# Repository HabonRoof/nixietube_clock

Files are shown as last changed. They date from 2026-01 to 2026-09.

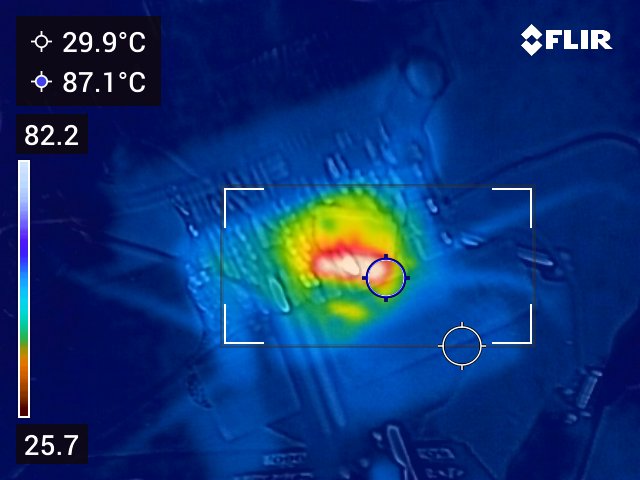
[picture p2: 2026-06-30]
doc/picture/tap_inductor/IR/FLIR0194.jpg

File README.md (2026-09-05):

# Nixie Clock Firmware

Open-source ESP-IDF firmware for a multiplexed Nixie clock powered by an ESP32-S3. Hardware display boards include IN-4 and IN-18 variants; at boot the firmware senses `DISPLAY_TYPE` (GPIO 19) and selects an IN-4 (6) or IN-14 (6/8) drive profile. RGB backlighting, audio playback, battery management, and a built-in web configuration UI are included.

Whether you want to hack on display effects, add CLI tools, improve the web UI, or bring up new hardware, this guide will get you building with [PlatformIO](https://platformio.org/) quickly.

## Features

- **Nixie display** — Multiplexed control via PCA9685 PWM drivers and a 74HC238 anode mux (tube count and chip count follow the detected display-board profile).
- **RGB backlight** — WS2812 addressable LEDs (4 per tube) with static, breath, rainbow, and off effects.
- **Audio** — DFPlayer Mini integration for sound effects and announcements.
- **RTC** — DS3231 for precise timekeeping with periodic resync to ESP32 system time.
- **Web UI** — On-demand config Wi-Fi AP (`NixieClock-XXXX` / `nixie2026`) with HTTP settings; long-press **button 1 + button 2** (3 s) to enter config mode.
- **NTP sync** — Optional home WiFi credentials; daily ~06:00 local brief STA session writes NTP to DS3231 and verifies RTC error < 1 min (retries on failure).
- **Buttons** — Debounced physical inputs for display mode, backlight profile, and interactive modes.
- **Hibernate mode** — Scheduled daily window turns off tubes and LED backlight. Press any button for a 5-second clock preview (tubes at fixed brightness 50, LED off).
- **Idle standby** — After 1 minute without button presses in clock mode, dim nixie and backlight brightness to 25% of the active profile; any button press restores full brightness.
- **Auto cathode anti-poisoning** — Every 15 minutes, run the same cathode-poisoning digit sweep as manual mode, then auto-return to the clock.
- **Serial CLI** — Interactive console for development, diagnostics, and power-rail control.
- **Power management** — BQ25601 battery charger, BQ27441 fuel gauge, and switched HV / DFPlayer rails.
- **Persistent settings** — Clock preferences stored in NVS and restored on boot.
- **Modular architecture** — FreeRTOS daemons coordinated by a central system controller.

## Developing with PlatformIO

This project uses **PlatformIO + ESP-IDF**. You can work from VS Code / Cursor or from the CLI.

### 1. Install tools

1. Install [Git](https://git-scm.com/) and [Python 3](https://www.python.org/downloads/) (needed for the git-version build script).
2. Install either:
   - **Recommended:** [VS Code](https://code.visualstudio.com/) or Cursor with the [PlatformIO IDE](https://platformio.org/install/ide?install=vscode) extension, or
   - [PlatformIO Core (CLI)](https://docs.platformio.org/en/latest/core/installation.html) alone.
   For now, the PlatformIO for cursor is not stable, so I recommand to use VSCode to compile and use Cursor for coding. 

Opening this repo in VS Code / Cursor should prompt you to install the recommended `platformio.platformio-ide` extension (see `.vscode/extensions.json`).

### 2. Clone and open the project

```bash
git clone https://github.com/HabonRoof/nixietube_clock.git
cd nixietube_clock
```

In VS Code / Cursor: **File → Open Folder** and select the repo root (the folder that contains `platformio.ini`).

First build will download the Espressif platform, ESP-IDF toolchain, and dependencies into `.pio/` — expect a few minutes on a clean machine.

### 3. Pick a build environment

Defined in `platformio.ini`:

| Environment | Board | Use case |
| :--- | :--- | :--- |
| `esp32_s3_devkitc_1` | ESP32-S3-DevKitC-1 | General development / bring-up |
| `esp32_s3_nixie` (default) | Custom `esp32-s3-nixie` (`boards/`) | Production Nixie clock board |

Switch the active env in the PlatformIO status bar, or pass `-e <name>` on the CLI.

### 4. Everyday commands

| Action | CLI | VS Code / Cursor (PlatformIO) |
| :--- | :--- | :--- |
| Build | `pio run` | Build (✓) |
| Flash | `pio run -t upload` | Upload (→) |
| Serial monitor | `pio run -t monitor` | Serial Monitor (🔌) |
| Build + flash + monitor | `pio run -t upload && pio run -t monitor` | Upload and Monitor |
| Clean | `pio run -t clean` | Clean |
| Build for Nixie board | `pio run -e esp32_s3_nixie` | Select `esp32_s3_nixie` env, then Build |

Serial monitor is **115200 baud** (8N1). After connect you should see boot logs and the CLI prompt `nixie_clock> `.

Useful PlatformIO tips:

```bash
# Rebuild from a clean slate
pio run -t clean && pio run

# Flash a specific env, then open the monitor
pio run -e esp32_s3_devkitc_1 -t upload
pio run -t monitor

# List detected serial ports if upload fails
pio device list
```

The build embeds the current git commit hash via `generate_git_version.py` (`get_fw_version` in the CLI).

### 5. Verify you are up and running

1. Flash firmware and open the serial monitor.
2. Type `help` at `nixie_clock> ` to list CLI commands.
3. **Long-press button 1 + button 2** (3 s together) to open the config Wi-Fi AP. Nixie tubes show a 4-digit session code; join `NixieClock-XXXX` (password `nixie2026`) and open `http://192.168.8.8/`.

If something fails to compile or upload, check:

- Use USB Type-A to Type-C cable, the hardware is not support to connect C to C cable for uploading.
- The board is in download mode / USB cable is data-capable.
- The correct env is selected (`esp32_s3_devkitc_1` vs `esp32_s3_nixie`).
- Python can run `generate_git_version.py` from the project root.
- Antivirus or missing udev/driver issues are not blocking the serial port (Windows often needs the CP2102 USB serial driver).

### 6. Where to start hacking

| Goal | Start here |
| :--- | :--- |
| Boot / wiring of subsystems | `src/main.cpp` |
| Mode logic, time, settings | `src/system_controller.*` |
| Tubes / LED effects | `src/daemons/display_daemon.*` |
| Buttons | `src/daemons/input_daemon.*` |
| Audio / DFPlayer | `src/daemons/audio_daemon.*` |
| Serial commands | `src/daemons/cli_daemon.*` |
| Web settings UI | `src/web_server.cpp`, `src/web_page.cpp` |
| Device drivers | `lib/drivers/`, `lib/include/` |
| Shared messages / state | `lib/include/message_types.h`, `src/system_state.*` |

## Software Structure

The firmware is split into clear layers so new contributors can find the right file quickly.

```text
┌─────────────────────────────────────────────────────────────┐
│  Interfaces                                                 │
│    WebServer  ·  CliDaemon  ·  InputDaemon (buttons)        │
├─────────────────────────────────────────────────────────────┤
│  Coordination                                               │
│    SystemController  ·  SystemState (NVS)                   │
├─────────────────────────────────────────────────────────────┤
│  FreeRTOS daemons                                           │
│    DisplayDaemon  ·  AudioDaemon                            │
├─────────────────────────────────────────────────────────────┤
│  App drivers / services                                     │
│    NixieDriver · LedDriver · AudioDriver                    │
│    PowerController · ChargerController · GasgaugeService    │
├─────────────────────────────────────────────────────────────┤
│  Hardware drivers (lib/drivers)                             │
│    PCA9685 · WS2812 · DFPlayer · DS3231 · BQ25601 · BQ27441 │
└─────────────────────────────────────────────────────────────┘
```

### Directory map

```text
nixietube_clock/
├── platformio.ini          # PlatformIO envs, ESP-IDF, build flags
├── boards/                 # Custom board JSON (esp32-s3-nixie)
├── generate_git_version.py # Embeds git hash into the firmware
│
├── src/                    # Application code (what most PRs touch)
│   ├── main.cpp            # Boot: NVS, drivers, start daemons
│   ├── system_controller.* # Central coordinator (time, modes, settings)
│   ├── system_state.*      # Thread-safe settings / battery / time + NVS
│   ├── web_server.*        # Wi-Fi AP + HTTP API
│   ├── web_page.*          # Embedded settings HTML/JS
│   ├── settings_json.*     # ClockSettings ↔ nested JSON
│   ├── web_json.*          # HTTP JSON body / response helpers
│   ├── nixie_driver.*      # High-level tube multiplexing
│   ├── led_driver.*        # High-level WS2812 control
│   ├── audio_driver.*      # High-level DFPlayer wrapper
│   ├── power_controller.*  # HV / DFPlayer rail switching
│   ├── charger_controller.*
│   ├── gasgauge_service.*
│   ├── color_model.cpp     # Color helpers for backlight
│   └── daemons/
│       ├── display_daemon.*  # Nixie + LED effects @ 50 Hz
│       ├── audio_daemon.*    # Async audio commands
│       ├── input_daemon.*    # Button debounce → SystemController
│       └── cli_daemon.*      # Serial console
│
├── lib/
│   ├── include/            # Public headers / interfaces / message types
│   └── drivers/            # Low-level IC drivers (I2C/UART/RMT/GPIO)
│       ├── pca9685/
│       ├── ws2812/
│       ├── dfplayer/
│       ├── ds3231/
│       ├── bq25601/
│       ├── bq27441/
│       ├── i2c_bus/
│       ├── power_switch/
│       └── display_board/
│
├── hardware/               # KiCad schematics & PCBs (main, display, HV)
├── test/                   # Manual CLI tests and component experiments
└── doc/                    # Datasheets, photos, architecture drawings
    ├── web_api.md          # HTTP JSON API schemas
    ├── state_machine.drawio  # Behavioral modes (keep in sync with firmware)
    └── structure.drawio    # Early aspirational block diagram (outdated)
```

### Responsibility cheat sheet

| Module | Role |
| :--- | :--- |
| `main.cpp` | Creates drivers/services, wires dependencies, starts tasks |
| `SystemController` | Owns RTC sync, display mode / backlight / alarm logic; single writer for settings |
| `SystemState` | Shared snapshots + NVS load/save |
| `DisplayDaemon` | Tube digits, LED effects, 50 Hz update loop |
| `AudioDaemon` | Plays/pauses tracks; powers DFPlayer rail via `PowerController` |
| `InputDaemon` | Polls/debounces BTN_0–2 and posts presses to `SystemController` |
| `CliDaemon` / `WebServer` | External control surfaces; request settings through `SystemController` |
| `lib/drivers/*` | Talk to chips; keep bus/register details out of app logic |

Cross-task communication uses FreeRTOS queues and types in `lib/include/message_types.h`. Prefer posting messages (or `SystemController::request_settings_update()`) over reaching into another daemon’s private state.

## Hardware Configuration

Pin assignments are defined in `src/system_controller.cpp` and `lib/drivers/power_switch/gpio_power_switch.h`.

| Peripheral | Pin Name | GPIO | Description |
| :--- | :--- | :--- | :--- |
| **I2C** | SDA | GPIO 6 | I2C data (DS3231, PCA9685, BQ25601, BQ27441) |
| | SCL | GPIO 5 | I2C clock (400 kHz) |
| **UART** | TX | GPIO 42 | Audio TX → DFPlayer RX |
| | RX | GPIO 41 | Audio RX ← DFPlayer TX |
| **GPIO** | RTC_INT | GPIO 2 | DS3231 interrupt (active low) |
| | BTN_0 | GPIO 8 | Alarm stop / pomodoro start / divergence re-trigger |
| | BTN_1 | GPIO 12 | Display mode cycle |
| | BTN_2 | GPIO 13 | Backlight profile cycle |
| | PCA_OE | GPIO 4 | PCA9685 output enable (active low) |
| | ANODE_A0–A2 | GPIO 9–11 | 74HC238 anode mux address lines |
| | DISPLAY_TYPE | GPIO 19 | Analog strap for display-board type (ADC2 CH8) |
| | HV_PWR | GPIO 15 | HV power rail enable (via `GpioPowerSwitch`) |
| | DF_PWR | GPIO 16 | DFPlayer power rail enable (via `GpioPowerSwitch`) |
| **RMT** | LED_DATA | GPIO 7 | WS2812 LED data line |

`DISPLAY_TYPE` strap voltages map to firmware profiles: ~0 V → IN-4 (6 tubes, 4× PCA9685); ~1.65 V → IN-14 (8 tubes, 5× PCA9685); ~3.3 V → IN-14 (6 tubes, 4× PCA9685). KiCad projects under `hardware/` include `display_board_in4` and `display_board_in18` (IN-18 boards use the matching strap / profile configured on the PCB).

## Architecture

The firmware runs on FreeRTOS and uses a daemon-based design. `SystemState` holds shared, thread-safe snapshots of settings, battery, and time status.

```mermaid
flowchart TB
    subgraph Interfaces
        Web[WebServer]
        CLI[CliDaemon]
        IN[InputDaemon]
    end

    SC[SystemController]
    DD[DisplayDaemon]
    AD[AudioDaemon]
    CC[ChargerController]
    PC[PowerController]

    Web --> SC
    CLI --> SC
    CLI --> CC
    CLI --> PC
    CLI --> AD
    IN --> SC

    SC --> DD
    SC --> AD
    SC --> SystemState[(SystemState / NVS)]

    DD --> Nixie[NixieDriver / PCA9685]
    DD --> LED[LedDriver / WS2812]
    AD --> Audio[AudioDriver / DFPlayer]
    AD --> PC
    SC --> RTC[DS3231]
    SC --> GG[GasgaugeService / BQ27441]
    CC --> Charger[BQ25601]
    PC --> Rails[HV & DFPlayer rails]
```

### System Controller (`src/system_controller.cpp`)

Central coordinator that:

- Initializes I2C, UART, RMT, and GPIO peripherals.
- Owns the DS3231 RTC and maintains ESP32 system time (UTC).
- Periodically resyncs from the RTC and publishes time status.
- Polls the BQ27441 fuel gauge and updates battery status.
- Dispatches 1 Hz time updates to `DisplayDaemon`.
- Handles button presses from `InputDaemon` (modes, backlight, pomodoro / alarm).
- Accepts thread-safe settings changes from the web UI and CLI.

### Display Daemon (`src/daemons/display_daemon.cpp`)

Manages all visual output:

- Drives Nixie tubes via `NixieDriver` (dedicated high-priority multiplexing task).
- Drives LED backlights via `LedDriver`.
- Runs the LED effects engine (static, breath, rainbow, off).
- Updates hardware at 50 Hz.

#### Display modes (BTN_1 cycle)

Press **BTN_1** to cycle through display modes in this order:

1. **Clock** (`HHMMSS`) — normal time display
2. **Date** (`YYMMDD`) — current date
3. **Pomodoro** — 25-minute work / 5-minute break timer
4. **Divergence meter** — random digit animation (auto-returns to clock)
5. **Cathode poisoning** — digit sweep on all tubes (auto-returns to clock)

**Pomodoro mode:** On entry the display shows `002500` with a static red backlight (brightness follows your profile). Press **BTN_0** to start the countdown; the backlight breathes red during work and green during break. Work and break sessions alternate automatically until you cycle away with **BTN_1**, which restores your backlight profile.

### Input Daemon (`src/daemons/input_daemon.cpp`)

Polls the three front-panel buttons every 20 ms with debounce / inter-press filtering, then posts press events to `SystemController`. **Button 2** short press cycles backlight profiles; **long press button 1 + button 2** (3 s) opens or closes the config Wi-Fi AP. Pin map: `lib/include/button_config.h`.

### Audio Daemon (`src/daemons/audio_daemon.cpp`)

Handles asynchronous audio commands (play, stop, volume) and communicates with the DFPlayer Mini. Uses `PowerController` to switch the DFPlayer power rail.

### Web Server (`src/web_server.cpp`, `src/web_page.cpp`)

On-demand config Wi-Fi AP and embedded HTTP server (active only in config mode):

| Setting | Value |
| :--- | :--- |
| Enter config | Long-press button 1 + button 2 for 3 s (same combo exits when AP is active) |
| SSID | `NixieClock-XXXX` (random 4-digit code each session; shown on Nixie tubes) |
| Password | `nixie2026` |
| AP IP | `192.168.8.8` |
| Timeout | 15 min max, or 2 min after all clients disconnect |

Connect to the AP and open `http://192.168.8.8/`. Use **完成並關閉設定 WiFi** when done.

| Endpoint | Method | Description |
| :--- | :--- | :--- |
| `/` | GET | Settings web UI |
| `/api/settings` | GET/POST | Clock settings (JSON); see [doc/web_api.md](doc/web_api.md) |
| `/api/ap/status` | GET | Config AP SSID, session code, remaining time |
| `/api/ap/stop` | POST | Stop config AP (deauth + shutdown) |
| `/api/wifi` | GET/POST/DELETE | Home WiFi for daily NTP sync |
| `/api/ntp/status` | GET | Last NTP sync status |
| `/api/time` | GET | Local time, RTC status, temperature |
| `/api/audio/*` | GET/POST | MP3 tracks and playback |

Home WiFi credentials enable a brief daily STA session at **06:00 local** for NTP → DS3231 sync (always write, verify RTC within 1 min, retry up to 3×); WiFi is off the rest of the time.

Full schemas: [doc/web_api.md](doc/web_api.md).

Configurable settings include timezone offset, alarm, backlight, nixie brightness/transition, volume, profiles, hibernation, and home WiFi. The web **Light** tab provides live display preview; **Save 1–4** commits a profile. Short-press button 2 to switch profiles on the device.

### CLI Daemon (`src/daemons/cli_daemon.cpp`)

Interactive serial console for development, diagnostics, and factory setup. Connect at **115200 baud** (8N1, no flow control) via USB or UART. The prompt is `nixie_clock> `. Type `help` for a summary of all commands.

```bash
pio run -t monitor
```

#### Display and backlight

| Command | Description |
| :--- | :--- |
| `set_nixie --number <n>` | Display a 6-digit number on the tubes |
| `set_backlight --rgb R,G,B --brightness N` | Set backlight color and brightness (0–255) |

#### Device info

| Command | Description |
| :--- | :--- |
| `get_uuid` | Wi-Fi MAC-based device ID |
| `get_hw_version` | ESP32-S3 chip and board revision |
| `get_fw_version` | Git commit hash and ESP-IDF version |
| `reboot` | Restart the device |

#### RTC and alarm (`rtctool`)

The DS3231 RTC stores **UTC** internally; CLI time and alarm values are **local wall clock** and are converted using the configured timezone offset. Set operations are asynchronous — run `rtctool read` afterward to confirm.

| Subcommand | Description |
| :--- | :--- |
| `rtctool read` | Read local time, UTC epoch, timezone, calibration/OSF status, temperature, and alarm settings |
| `rtctool set_tz <offset_hours>` | Set timezone offset (-12..+14) |
| `rtctool set_time <YYYY-MM-DD HH:MM:SS>` | Calibrate RTC and system clock (marks RTC as calibrated) |
| `rtctool set_alarm <HH:MM:SS> [--enable\|--disable] [--track <n>]` | Set daily alarm time; enables alarm by default |

Example workflow:

```text
nixie_clock> rtctool set_tz 8
nixie_clock> rtctool set_time 2026-07-06 16:30:00
nixie_clock> rtctool set_alarm 07:30:00 --enable --track 1
nixie_clock> rtctool read
```

To disable the alarm without changing its time:

```text
nixie_clock> rtctool set_alarm 07:30:00 --disable
```

#### Power and charging

| Command | Description |
| :--- | :--- |
| `get_bq25601_status` | Read BQ25601 charger status registers |
| `enable_charging` / `disable_charging` | Control battery charging |
| `enable_hv` / `disable_hv` | Control HV power rail |
| `enable_df_power` / `disable_df_power` | Control DFPlayer power rail |

#### DFPlayer audio (`dftool`)

Commands talk to the `AudioDaemon`, which powers the DFPlayer rail automatically when needed. Place MP3 files in an `mp3` folder on the SD card root and name them `0001.mp3`, `0002.mp3`, etc. (up to 9999). Track numbers match the numeric prefix in each filename.

| Subcommand | Description |
| :--- | :--- |
| `dftool list` | List tracks in the SD card `mp3/` folder |
| `dftool status` | Show current track, playback state, and track count |
| `dftool play <track> [--loop]` | Play a track; add `--loop` for repeat |
| `dftool toggle <track>` | Play/pause toggle (same behavior as the web UI) |
| `dftool pause` | Pause playback |
| `dftool resume` | Resume playback |
| `dftool stop` | Stop playback |
| `dftool next` | Play next track |
| `dftool prev` | Play previous track |
| `dftool volume <0-30>` | Set volume (DFPlayer range) |
| `dftool vol_up` / `dftool vol_down` | Step volume up or down |

Example workflow:

```text
nixie_clock> dftool list
nixie_clock> dftool play 1
nixie_clock> dftool status
nixie_clock> dftool pause
nixie_clock> dftool resume
nixie_clock> dftool volume 20
nixie_clock> dftool stop
```

#### Fuel gauge (`ggtool`)

| Subcommand | Description |
| :--- | :--- |
| `ggtool status` | Probe BQ27441 device info and gauging readiness |
| `ggtool read` | Read live SOC, SOH, voltage, and current |
| `ggtool cache` | Read last cached battery values from `SystemState` |
| `ggtool peek <reg_hex> [len]` | Dump raw register bytes |
| `ggtool block [class] [index]` | Dump a 32-byte state block |
| `ggtool config [mAh]` | Configure design capacity |

See `test/test_cli/README.md` for a manual test plan and automated test script.

### Drivers (`lib/drivers/`, `src/*_driver.cpp`)

| Driver | Role |
| :--- | :--- |
| `NixieDriver` | PCA9685 multiplexing; chip/tube count from `display_board_config` profile |
| `LedDriver` | RMT-based WS2812 control |
| `AudioDriver` | High-level DFPlayer Mini interface |
| `Ds3231` | RTC read/write and temperature |
| `Bq25601` | Battery charger IC |
| `Bq27441` | Fuel gauge IC |
| `GpioPowerSwitch` | HV and DFPlayer power-rail switching |

## Development Guide

### Adding a New LED Effect

1. Add a method such as `run_my_effect(uint32_t dt_ms)` in `DisplayDaemon`.
   Use `apply_backlight_to_all(state)` or manipulate `led_driver_` directly.
2. Add an entry to the `LedEffectType` enum in `display_daemon.h`.
3. Update `DisplayDaemon::process_message` to handle the new effect type.
4. Update `DisplayDaemon::update_effects` to call the new method.
5. Expose the effect in the web UI (`web_page.cpp`) and settings schema (`system_state.h`).

### Applying Settings from a New Interface

Use `SystemController::request_settings_update()` so the system controller task remains the sole owner of RTC and settings state. Read current values from `SystemState` and persist with `SystemState::save_settings()`.

### Adding a CLI Command

1. Register parsing / help text in `src/daemons/cli_daemon.cpp`.
2. Prefer calling existing controllers/daemons (`SystemController`, `AudioDaemon`, `PowerController`, …) instead of talking to hardware directly.
3. Document the command in this README under **CLI Daemon**.

## Contributing

Contributions are welcome — effects, CLI tools, web UI polish, driver fixes, docs, and hardware errata all help.

1. Fork the repo and create a feature branch.
2. Build with PlatformIO (`pio run`) and smoke-test on hardware or a DevKit when possible.
3. Keep changes focused; match the existing modular daemon style.
4. Open a pull request describing **what** changed and **how to test** it.

If you are unsure where something belongs, open an issue first — happy to point you at the right module.

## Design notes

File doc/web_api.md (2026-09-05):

# Web API

HTTP JSON API served when the Nixie clock config Wi-Fi AP is active (`NixieClock-XXXX` / `192.168.8.8`). Enter config mode with a **3 s long-press on button 1 + button 2 together**.

All JSON endpoints use `Content-Type: application/json`. Successful mutations return `{"ok": true}`. Errors return HTTP 4xx/5xx with:

```json
{
  "ok": false,
  "error": {
    "code": "invalid_type",
    "field": "alarm.time",
    "message": "must be a string"
  }
}
```

`field` is omitted when the error is not tied to a specific key.

Maximum POST body size: **4096 bytes**.

## Endpoints

| Endpoint | Method | Description |
| :--- | :--- | :--- |
| `/` | GET | Embedded settings web UI (HTML) |
| `/api/settings` | GET | Current persisted settings |
| `/api/settings` | POST | Apply a partial settings update |
| `/api/time` | GET | Live clock readout and RTC health |
| `/api/audio/tracks` | GET | MP3 track list from SD card |
| `/api/audio/status` | GET | Current playback state |
| `/api/audio/play` | POST | Toggle play/pause for a track |
| `/api/ap/status` | GET | Config AP active flag, SSID, password, session code, remaining seconds |
| `/api/ap/stop` | POST | Deauth connected clients and stop config AP |
| `/api/wifi` | GET | Home WiFi SSID (configured flag; password never returned) |
| `/api/wifi` | POST | Save home WiFi credentials to NVS |
| `/api/wifi` | DELETE | Clear home WiFi credentials |
| `/api/ntp/status` | GET | Last NTP sync timestamp and success flag |

## `GET /api/ap/status`

```json
{
  "active": true,
  "session_code": 3847,
  "ssid": "NixieClock-3847",
  "password": "nixie2026",
  "remaining_sec": 842,
  "client_count": 1
}
```

## `POST /api/ap/stop`

Stops the config AP after deauthenticating connected stations. Response: `{"ok": true}`.

## `GET /api/wifi`

```json
{
  "configured": true,
  "ssid": "MyHomeWiFi"
}
```

## `POST /api/wifi`

```json
{
  "ssid": "MyHomeWiFi",
  "password": "secret"
}
```

## `DELETE /api/wifi`

Clears stored home WiFi credentials. NTP scheduled sync is skipped until reconfigured.

## `GET /api/ntp/status`

```json
{
  "configured": true,
  "last_success": true,
  "last_ntp_unix": 1736123456
}
```

## `GET /api/settings`

```json
{
  "schema_version": 1,
  "clock": {
    "timezone_offset_hours": 8,
    "rtc_calibrated": true
  },
  "alarm": {
    "enabled": true,
    "time": "07:30:00",
    "track": 1
  },
  "display": {
    "backlight": {
      "color": { "r": 255, "g": 128, "b": 0 },
      "brightness": 128,
      "effect": "static"
    },
    "nixie": {
      "brightness": 255,
      "transition": "fade"
    }
  },
  "audio": { "volume": 15 },
  "profiles": {
    "active_index": 0,
    "items": [
      { "index": 0, "display": { "...": "..." } }
    ]
  },
  "hibernation": {
    "enabled": false,
    "start": "00:00",
    "end": "07:00"
  }
}
```

### Field reference

| Path | Type | Range / values |
| :--- | :--- | :--- |
| `schema_version` | integer | API schema version (currently `1`) |
| `clock.timezone_offset_hours` | integer | `-12` … `14` |
| `clock.rtc_calibrated` | boolean | `true` after explicit time sync |
| `alarm.enabled` | boolean | |
| `alarm.time` | string | `HH:MM:SS` (local wall clock) |
| `alarm.track` | integer | DFPlayer track number (`1` … `9999`) |
| `display.backlight.color.{r,g,b}` | integer | `0` … `255` |
| `display.backlight.brightness` | integer | `0` … `255` |
| `display.backlight.effect` | string | `static`, `breath`, `rainbow`, `off` |
| `display.nixie.brightness` | integer | `0` … `255` |
| `display.nixie.transition` | string | `instant`, `fade` |
| `audio.volume` | integer | `0` … `30` (DFPlayer hardware range) |
| `profiles.active_index` | integer | `0` … `3` |
| `profiles.items[].index` | integer | Profile slot `0` … `3` |
| `hibernation.enabled` | boolean | |
| `hibernation.start` / `end` | string | `HH:MM` (local time) |

`display` reflects the **active** profile's nixie settings and the top-level backlight fields.

## `POST /api/settings`

Send only the groups you want to change. Unknown keys are rejected.

`persist` defaults to `true`. When `persist` is `false`, only a `display` preview may be sent; settings are applied to the hardware immediately but **not** written to NVS. After **2 seconds** without a newer preview, the device automatically restores the active saved profile on the hardware.

### Examples

Live display preview (RAM only, not saved):

```json
{
  "display": { "...": "..." },
  "persist": false
}
```

Discard an active web preview immediately and restore the committed active profile:

```json
{
  "preview": { "cancel": true }
}
```

Set volume only:

```json
{ "audio": { "volume": 20 } }
```

Sync RTC from the browser's local clock:

```json
{
  "clock": {
    "timezone_offset_hours": 8,
    "local_time": "2026-07-13 16:30:00"
  }
}
```

Save current display to profile slot 2 (also activates slot 2):

```json
{
  "display": { "...": "..." },
  "profiles": { "save_index": 2 },
  "persist": true
}
```

Update hibernation schedule:

```json
{
  "hibernation": {
    "enabled": true,
    "start": "23:00",
    "end": "07:00"
  }
}
```

### `profiles` semantics

| Field | Behavior |
| :--- | :--- |
| `save_index` | Copies the current display state (after any `display` fields in the same request) into the given slot and makes it active. Requires `persist: true` (default). |

On the device, switch the active profile with **button 2** (not the web UI).

### Web UI behavior

- The **Light** tab sends `persist: false` display previews while sliders move (throttled live updates via pointer events; flush on pointer up).
- Each preview restarts a **2 second** device-side timer; when the timer expires without a newer preview, the active saved profile is restored on the hardware (form values stay so Save can still commit).
- **Save 1–4** commits the preview to a profile slot with `persist: true` and clears the preview timer.
- Leaving the Light tab or closing the browser cancels the preview via `preview.cancel` and restores the active saved profile (and the form from the last committed display).

## `GET /api/time`

```json
{
  "local_time": "2026-07-13 16:30:00",
  "unix_utc": 1783938600,
  "time_valid": true,
  "osf": false,
  "temperature": 25.50,
  "clock": {
    "timezone_offset_hours": 8,
    "rtc_calibrated": true
  }
}
```

| Field | Description |
| :--- | :--- |
| `local_time` | Current local wall-clock string |
| `unix_utc` | UTC epoch seconds |
| `time_valid` | Whether the RTC/system time is considered valid |
| `osf` | DS3231 oscillator-stop flag (backup power lost) |
| `temperature` | DS3231 temperature (°C) |
| `clock.timezone_offset_hours` | Configured timezone offset |
| `clock.rtc_calibrated` | Same meaning as in `/api/settings` |

## Audio endpoints

### `GET /api/audio/tracks`

```json
{
  "folder": "mp3",
  "count": 3,
  "tracks": [
    { "id": 1, "name": "mp3/0001.mp3" }
  ]
}
```

On SD read failure, `count` is `0`, `tracks` is `[]`, and `error` is `"query_failed"`.

### `GET /api/audio/status`

```json
{ "track": 1, "state": "playing", "count": 3 }
```

`state` is `playing`, `paused`, or `stopped`.

### `POST /api/audio/play`

```json
{ "track": 1 }
```

Response:

```json
{ "track": 1, "state": "playing" }
```

## Migration from the flat JSON API

The previous API used flat keys and numeric enums. Key changes:

| Old (GET/POST) | New |
| :--- | :--- |
| `tz_offset` | `clock.timezone_offset_hours` |
| `time` (POST) | `clock.local_time` |
| `alarm_enabled` | `alarm.enabled` |
| `alarm_time` | `alarm.time` |
| `alarm_track` | `alarm.track` |
| `backlight_rgb` (`"r,g,b"`) | `display.backlight.color` object |
| `backlight_brightness` | `display.backlight.brightness` |
| `backlight_effect` (`0`–`3`) | `display.backlight.effect` (string) |
| `nixie_brightness` | `display.nixie.brightness` |
| `nixie_transition` (`0`/`1`) | `display.nixie.transition` (`instant`/`fade`) |
| `volume` | `audio.volume` |
| `save_profile_index` | `profiles.save_index` |
| `profiles` (array) | `profiles.items` (array of `{index, display}`) |
| `active_profile_index` (GET) | `profiles.active_index` |
| POST success body `"OK"` | `{"ok": true}` |
| `/api/time` `tz_offset` | `clock.timezone_offset_hours` |
| `/api/time` `rtc_calibrated` (top-level) | `clock.rtc_calibrated` |

Clients should check `schema_version` on `GET /api/settings` before parsing.

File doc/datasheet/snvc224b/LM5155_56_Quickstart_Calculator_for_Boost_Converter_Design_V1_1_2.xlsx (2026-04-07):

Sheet: Design Converter
 | LM5155/56 DC/DC BOOST Controller Design Tool
ABOUT |  | =Input Box |  |  |  |  | TERMS OF USE
 |  |  |  |  |  |  | Rev 1.1.1 | August-2021
Step 1: Design Specifications
 |  |  | Minimum Input Supply Voltage , VSUPPLY(min) | 4.8 | V
 |  |  | Typical Input Supply Voltage, VSUPPLY(typ) | 12 | V
 |  |  | Maximum Input Supply Voltage , VSUPPLY(max) | 18 | V
 |  |  | Target Output Voltage, VLOAD | 173 | V
 |  |  | Maximum Output Current , ILOAD | 0.015 | A
 |  |  | Free Running Switching Frequency, FSW | 100 | kHz
 |  |  | Free running Oscillator Set Resistor, RT | 220.04 | kΩ
 |  |  | Estimated Efficiency | 95 | %
 |  |  | Output Power, POUT | 2.595 | W
 |  |  | Boost Converter Duty Cycle Limit by LM5155 at VSUPPLY(MIN) | 93 | %
 |  |  | Ideal Duty Cycle at VSUPPLY(MIN) | 97.22543353 | %
 |  |  | Operation Mode | DCM
Step 2: Filter Inductor
 |  |  | Desired Maximum Inductor Current Ripple Ratio (IRR_MAX) | 60 | %
 |  |  | Recommended Inductance (LM_CALC) | 43.161 | μH
 |  |  | User Selection. Inductance, (LM) | 10 | μH
 |  |  | Max Inductor DCR, RDCR | 35 | mΩ
 |  |  | Peak inductor current, ILPK | 2.25 | A
Step 3: Current Sense Resistor Selection
 |  |  | Peak Current Limit Margin | 20 | %
 |  |  | Selected Peak Current limit(ILPK_select) | 2.70 | A
 |  |  | Recommended current sense Resistor (RS) | 37.10 | mΩ
 |  |  | Recommended external slope compensation Resistor (RSL) | 0 | Ω
 |  |  | Selected current sense Resistor (RS) | 33 | mΩ
 |  |  | Selected external slope compensation Resistor (RSL) | 0 | Ω
 |  |  | Actual inductor peak current limit | 3.03 | A
 |  |  | Recommend Minimum Inductor Saturation Current Rating | 3.48 | A
Step 4: Output Capacitor Selection
 |  |  | Desired Output ripple voltage (ΔvOUT) | 100 | mV
 |  |  | Minimum output capacitance | 0.70 | μF
 |  |  | Capacitor RMS current (IRMS_COUT) | 0.95 | A
 |  |  | Selected Output Capacitance (COUT) | 10 | μF
 |  |  | Equivalent COUT ESR (RESR) | 28000 | mΩ
Step 5: Soft-Start Capacitor Selection
 |  |  | Suggested minimum soft-start capacitor (CSS_MIN) | 1153.33 | nF
 |  |  | Desired soft-start time at minimum input voltage (TSS) | 17 | ms
 |  |  | Calculated soft-start capacitor (CSS) | 174.8513674 | nF
Step 6: UVLO Resistor Divider Selection
 |  |  | Desired voltage On (VUVLO_ON) | 4.5 | V
 |  |  | Desired voltage OFF (VUVLO_OFF) | 4.1 | V |  |  |  | 4.8
 |  |  | Calculated top UVLO resistor value (RUVT_CALC) | 50.30 | kΩ
 |  |  | Selected top UVLO resistor value (RUVT) | 50 | kΩ
 |  |  | Bottom UVLO Resistor (RUVB) | 25.000 | kΩ
Step 7: Loop Compensation
 |  |  | Voltage selected (VIN_VAR) | 12V
 |  |  | Feedback Resistor Selection
 |  |  | Select a top feedback resistor(RFBT) | 1000 | kΩ
 |  |  | Calculated bottom feedback resistor (RFBB_cala) | 5.81 | kΩ
 |  |  | Select a bottom resistor based on calculated value(RFBB) | 5.75 | kΩ
 |  |  | Suggested maximum bandwidth | 10.0 | kHz
 |  |  | Selected bandwidth (FCO) | 1 | kHz
 |  |  |  |  |  | Crossover Frequency = 66.1 kHz
 |  | Calculated |  | Selected |  | Phase Margin = -96°
 | RCOMP | 22.3 | kΩ | 22 | kΩ
 | CCOMP | 136.02 | nF | 120 | nF
 | CHF | 50.58890038 | pF | 50 | pF
Efficiency / Power Loss Analyzer
MOSFET parameters
 |  |  | On-State Resistance, RDS(on) | 126 | mΩ
 |  |  | Total Gate Charge, QG | 45 | nC
 |  |  | Gate-Drain Charge, QGD | 8 | nC
 |  |  | Gate-Source Charge, QGS | 9 | nC
 |  |  | Gate Resistance, RG | 0.7 | Ω
 |  |  | Transconductance, gFS | 15.1 | S
 |  |  | Gate-Source Threshold Voltage, VTH | 3 | V
Diode Parameters
 |  |  | Recommended minimum average current rating (ID_AVG) | 0.015 | A
 |  |  | Forward Voltage Drop (VD) | 1250 | mV
 |  |  | Reverse recovery charge of Schottky Diode (QRR) | 17 | nC

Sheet: Licenses
Version Number | 1.1.1
Version History
Version | Change List Description
1.0.0 | Initial Release
1.1.0 | Added DCM mode
1.1.1 | Fixed reporting of wrong phase Margin

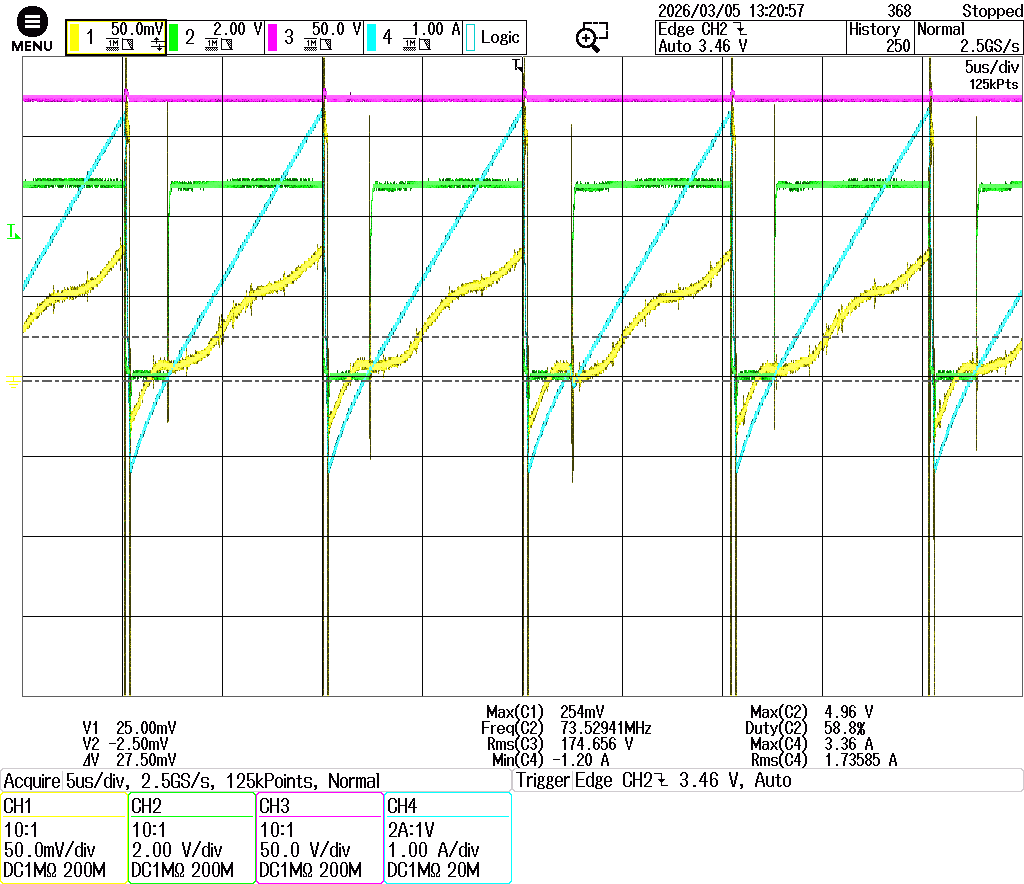
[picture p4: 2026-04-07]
doc/picture/single_board/waveform/175V20mARsen23p5000.png

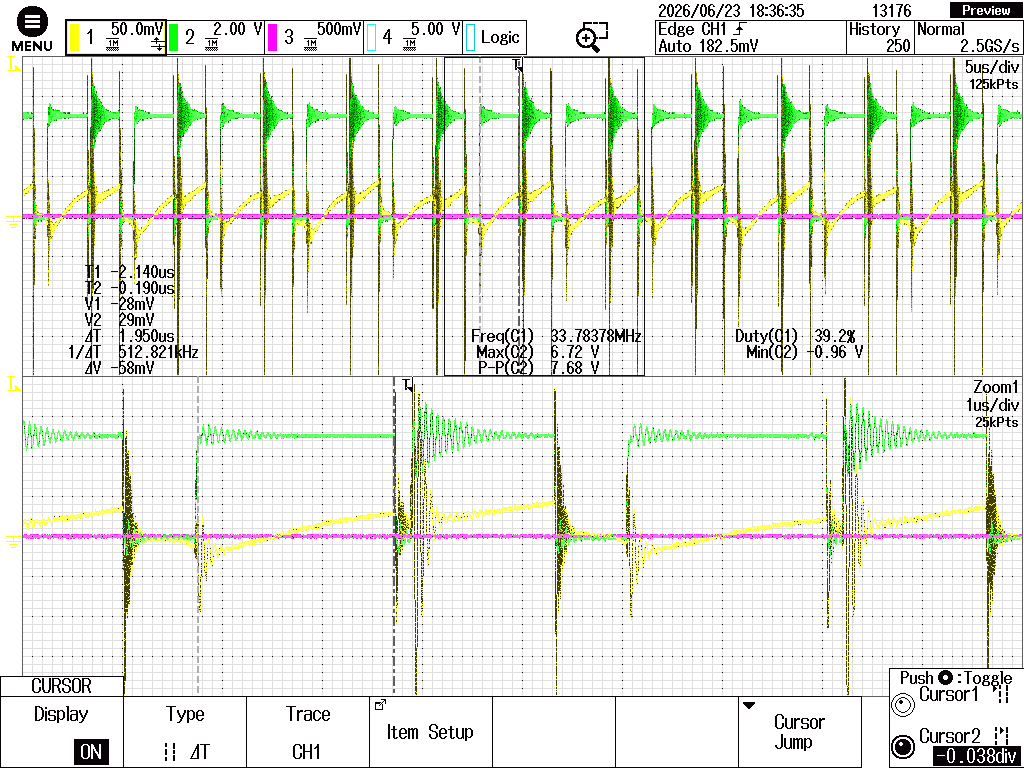
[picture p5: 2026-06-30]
doc/picture/tap_inductor/155uH_N2/150V5mA003.png

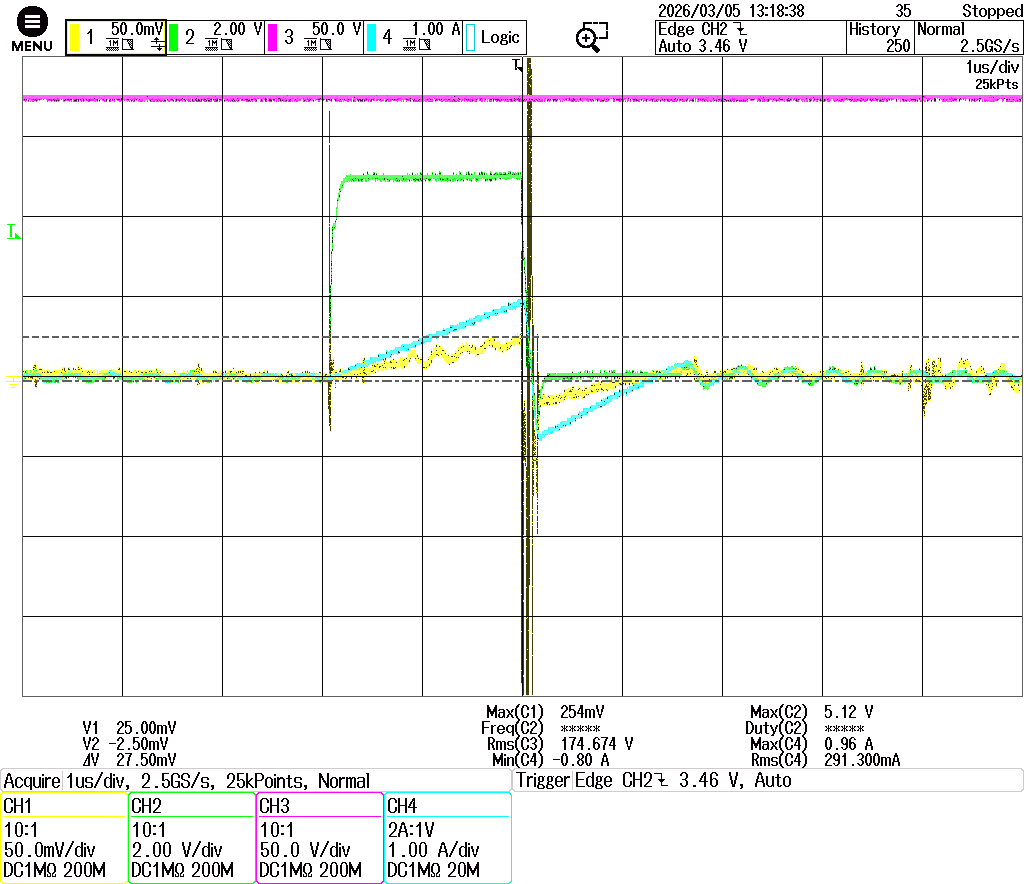
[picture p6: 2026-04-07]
doc/picture/single_board/waveform/175V0ARsen23p5001.png

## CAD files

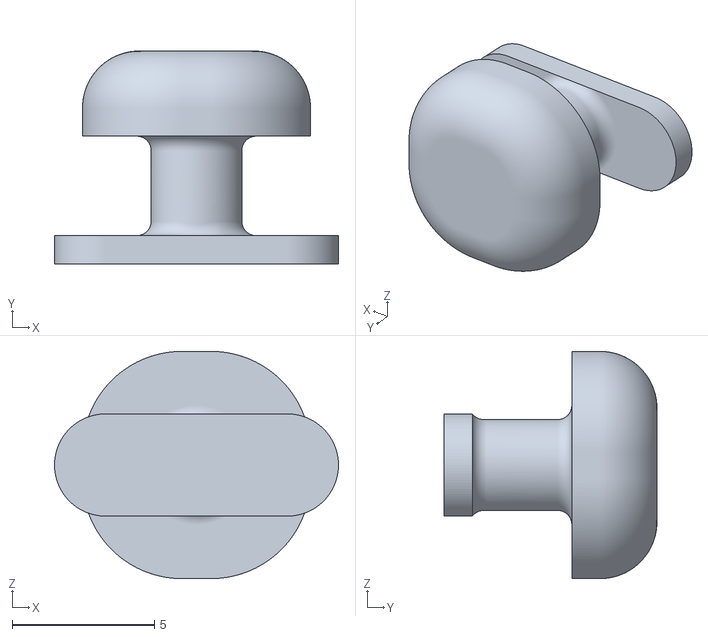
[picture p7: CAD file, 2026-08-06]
hardware/case/按鈕 - S.STL
10.0 x 7.50 x 8.00

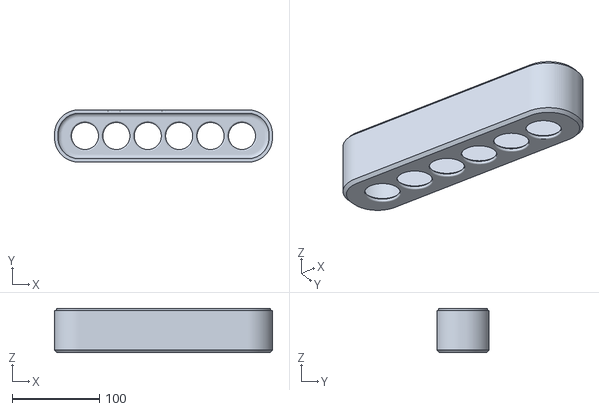
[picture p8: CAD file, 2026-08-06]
hardware/case/OUTBOXX_B.STL
250.0 x 60.0 x 51.0

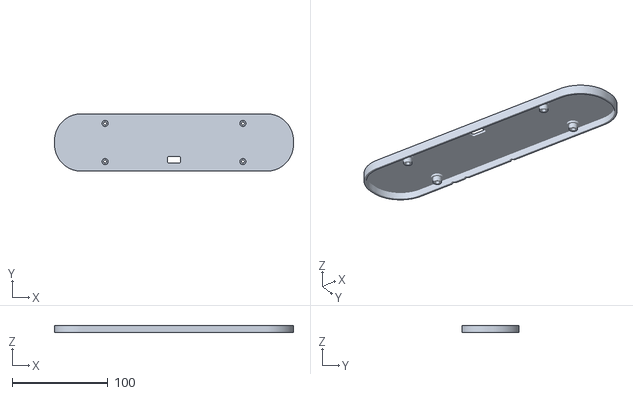
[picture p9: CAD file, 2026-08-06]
hardware/case/OUTBOXX_F.STL
250.0 x 60.0 x 7.50

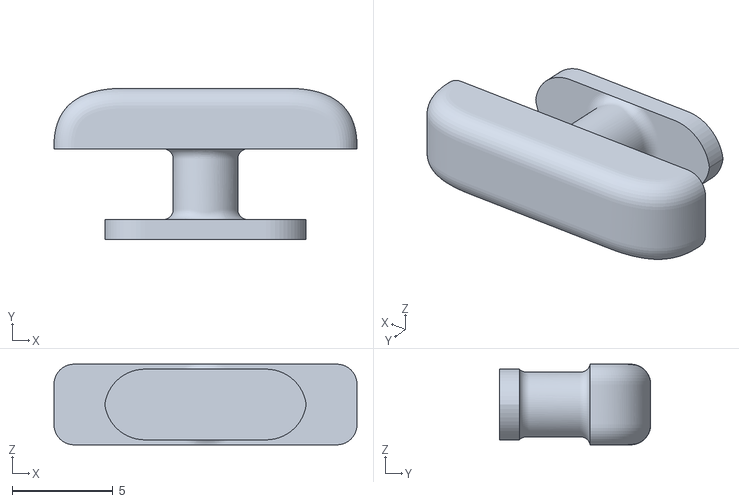
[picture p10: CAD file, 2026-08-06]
hardware/case/按鈕-L.STL
15.0 x 7.50 x 4.00

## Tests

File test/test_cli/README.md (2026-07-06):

# CLI Test Plan

This document outlines the test plan for the Nixie Clock CLI.

## Prerequisites

1.  **Hardware**: Nixie Clock device connected via USB/UART.
2.  **Software**: Python 3 installed on the host machine.
3.  **Dependencies**: `pyserial` library (`pip install pyserial`).

## Manual Testing

1.  **Connect**: Open a serial terminal (e.g., PuTTY, screen, or VSCode Serial Monitor) to the device's COM port at 115200 baud.
2.  **Help**: Type `help` and press Enter. Verify that `nixie_clock` is listed.
3.  **Set Nixie Number**:
    *   Command: `set_nixie --number 123456`
    *   Expected Result: The Nixie tubes should display `123456`.
4.  **Set Backlight Color (Red)**:
    *   Command: `set_backlight --rgb 255,0,0 --brightness 255`
    *   Expected Result: The backlight LEDs should turn bright red.
5.  **Set Backlight Color (Green, Dim)**:
    *   Command: `set_backlight --rgb 0,255,0 --brightness 50`
    *   Expected Result: The backlight LEDs should turn dim green.
6.  **Get UUID**:
    *   Command: `get_uuid`
    *   Expected Result: Output similar to `UUID: AABBCCDDEEFF`.
7.  **Get HW Version**:
    *   Command: `get_hw_version`
    *   Expected Result: Output similar to `HW Version: ESP32-S3 (Rev 1), Board: v1.0`.
8.  **Get FW Version**:
    *   Command: `get_fw_version`
    *   Expected Result: Output similar to:
        ```
        App Version: a1b2c3d...
        IDF Version: v5.x.x...
        ```
9.  **Invalid Command**:
    *   Command: `set_nixie --number` (missing value)
    *   Expected Result: Error message indicating missing argument.
10. **RTC Read**:
    *   Command: `rtctool read`
    *   Expected Result: Local time, timezone, calibration/OSF flags, temperature, and alarm settings.
11. **RTC Set Timezone**:
    *   Command: `rtctool set_tz 8`
    *   Expected Result: `Timezone offset set to +8 h`.
12. **RTC Calibrate**:
    *   Command: `rtctool set_time 2026-07-06 16:30:00`
    *   Expected Result: `RTC calibration requested: ...` then `rtctool read` shows the new local time.
13. **RTC Set Alarm**:
    *   Command: `rtctool set_alarm 07:30:00 --enable --track 1`
    *   Expected Result: `Alarm update requested: 07:30:00 enabled (track 1)`.
14. **RTC Disable Alarm**:
    *   Command: `rtctool set_alarm 07:30:00 --disable`
    *   Expected Result: `Alarm update requested: ... disabled`.

## Automated Testing

A Python script `test_cli.py` is provided to automate sending commands.

### Usage

```bash
python test_cli.py <port>
```

Example:
```bash
python test_cli.py /dev/ttyUSB0
```

The script will send a sequence of commands and prompt you to verify the visual output on the device.

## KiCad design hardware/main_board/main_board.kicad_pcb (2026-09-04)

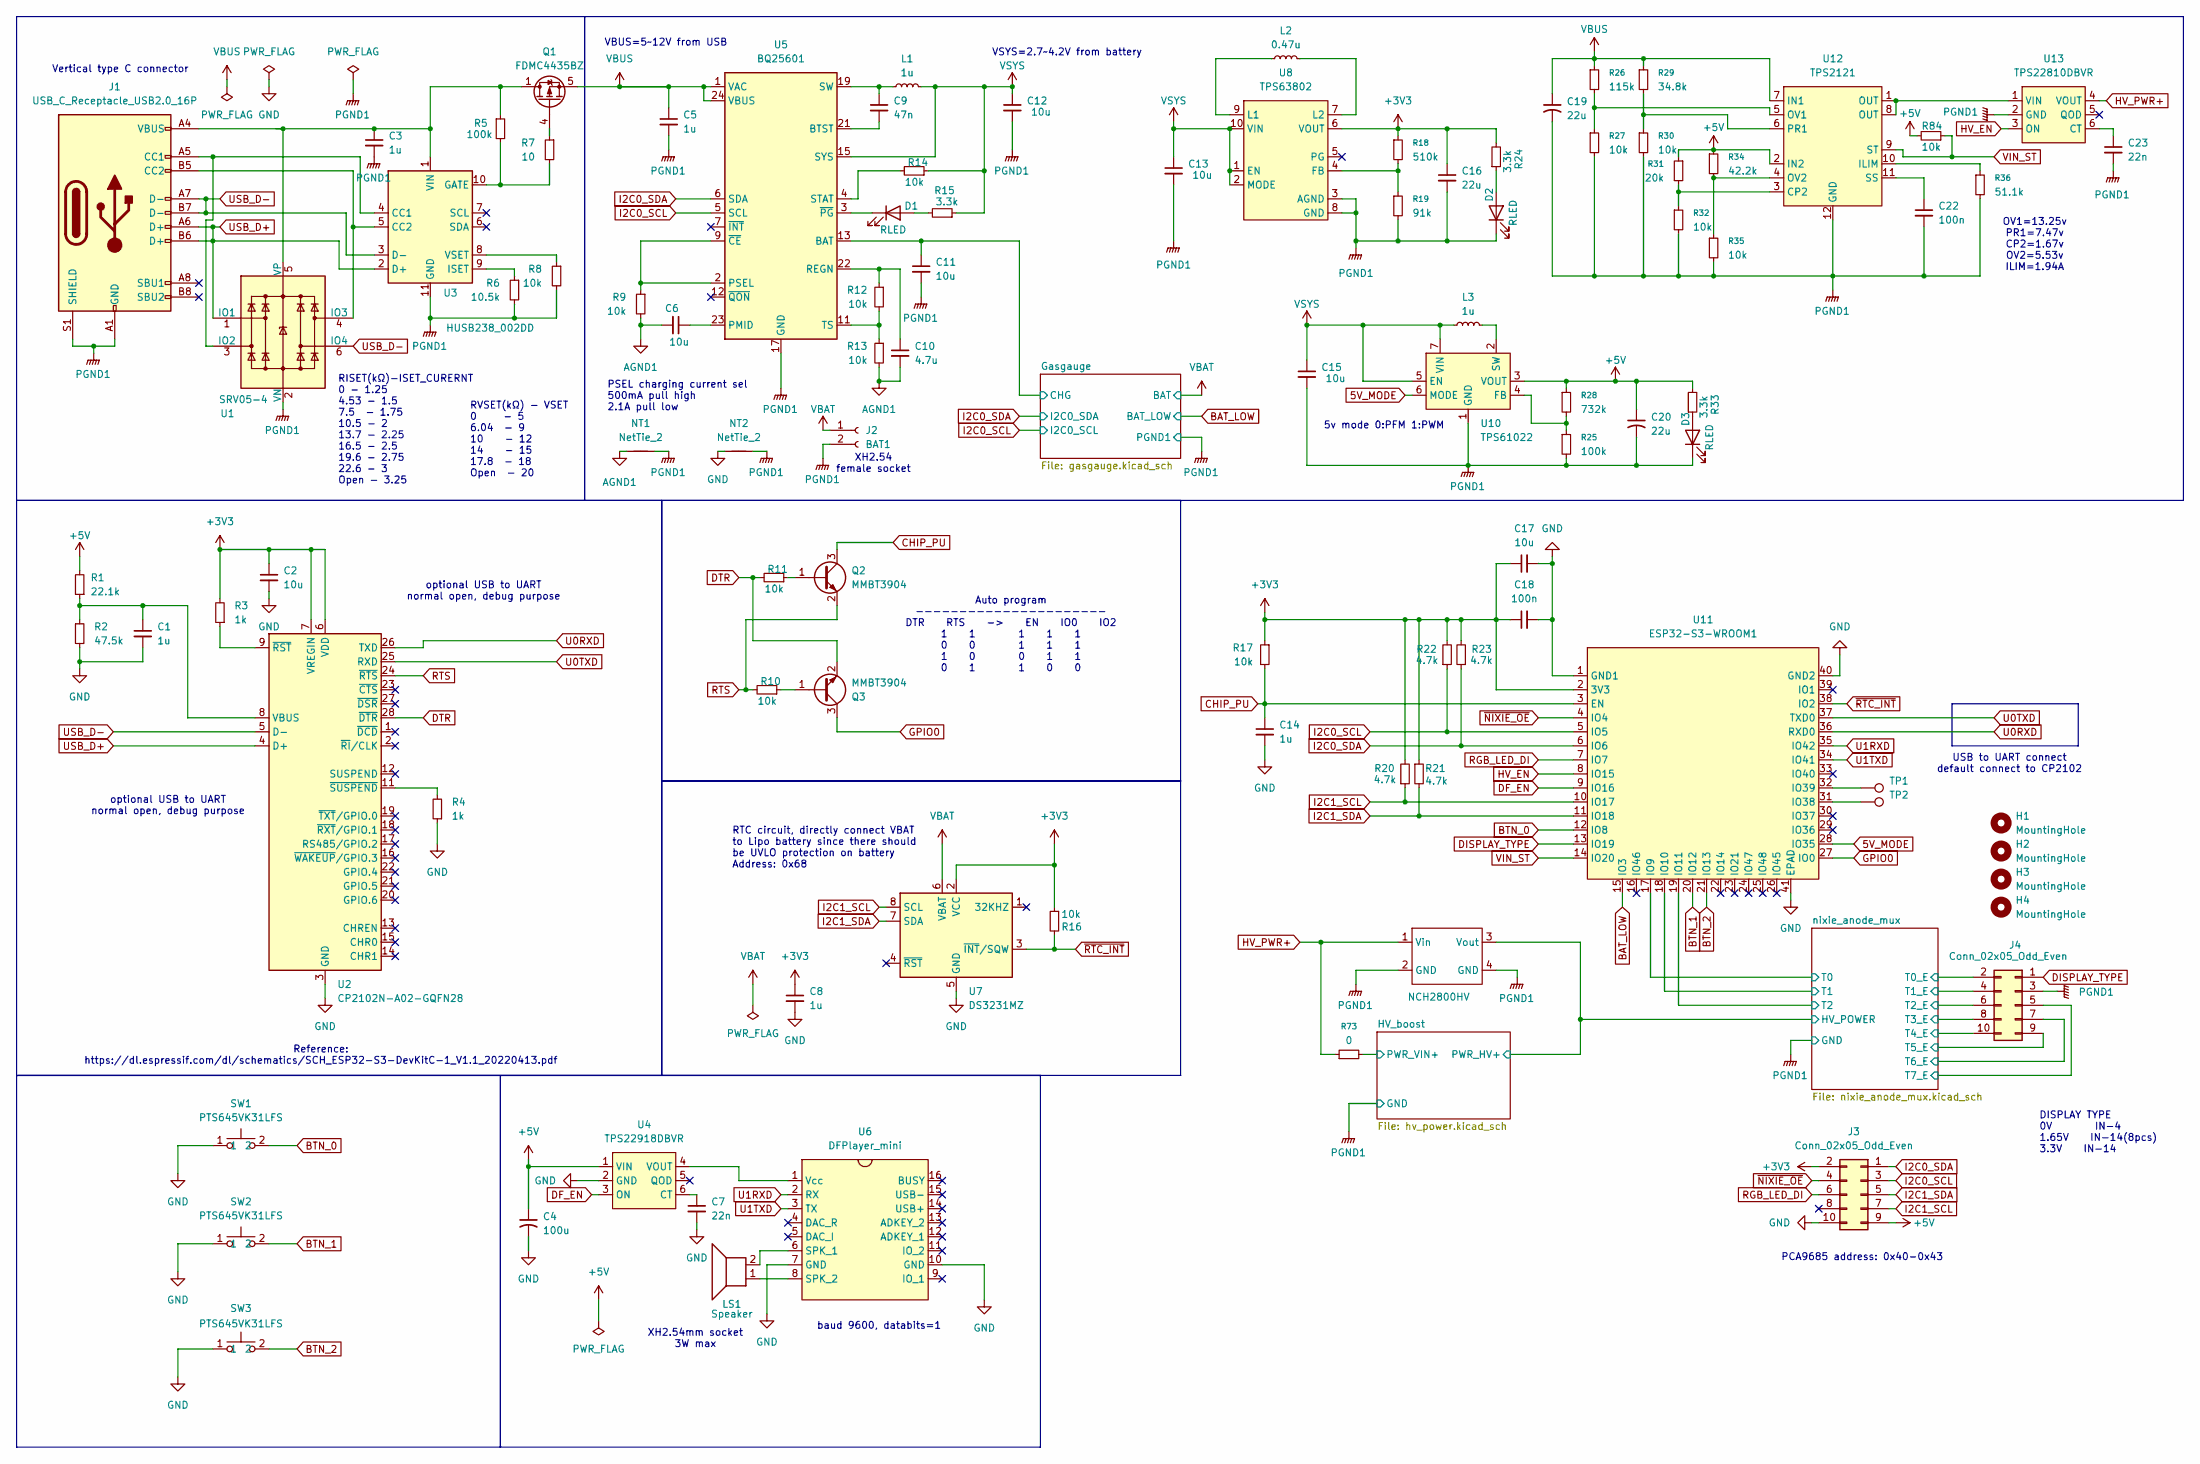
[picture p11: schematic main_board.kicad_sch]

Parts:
C1, C3, C5, C8, C14: 1u; C_0603_1608Metric; LCSC PN C5199872
C2, C6, C11, C17: 10u; C_0603_1608Metric; LCSC PN C19702
C4: 100u; C_Elec_6.3x5.4; LCSC PN C2887276
C7: 22n; C_0603_1608Metric; LCSC PN C106222
C9: 47n; C_0603_1608Metric; LCSC PN C1622
C10: 4.7u; C_0603_1608Metric; LCSC PN C18185770
C12: 10u; C_0805_2012Metric; LCSC PN C6119932
C13, C15: 10u; CP_EIA-2012-12_Kemet-R; LCSC PN C129234
C16: 22u; C_0805_2012Metric; LCSC PN C23692981
C18, C22: 100n; C_0402_1005Metric; LCSC PN C1525
C19, C20: 22u; C_Elec_5x5.4; LCSC PN C970662
C23: 22n; C_0402_1005Metric; LCSC PN C1532
D1, D2, D3: RLED; LED_0603_1608Metric; LCSC PN C2286
H1, H2, H3, H4: MountingHole; MountingHole_3.2mm_M3_DIN965
J1: USB_C_Receptacle_USB2.0_16P; USB_C_Receptacle_G-Switch_GT-USB-7051x; LCSC PN C2843970
J2: BAT1; JST_PH_S2B-PH-SM4-TB_1x02-1MP_P2.00mm_Horizontal; LCSC PN C3029440
J3, J4: Conn_02x05_Odd_Even; PinHeader_2x05_P2.00mm_Vertical; LCSC PN C42385473
L1: 1u; L_Wuerth_PMCI-252010; LCSC PN C696436
L2: 0.47u; Murata_201612E; LCSC PN C668312
L3: 1u; L_Coilcraft_XAL6030-XXX; LCSC PN C5157561
LS1: Speaker; JST_PH_S2B-PH-SM4-TB_1x02-1MP_P2.00mm_Horizontal; LCSC PN C3029440
NT1, NT2: NetTie_2; NetTie-2_SMD_Pad0.5mm
Q1: FDMC4435BZ; VSON-8_3.3x3.3mm_P0.65mm_NexFET; LCSC PN C556450
Q2, Q3: MMBT3904; SOT-23; LCSC PN C81464
R1: 22.1k; R_0402_1005Metric; LCSC PN C43473
R2: 47.5k; R_0402_1005Metric; LCSC PN C103064
R3, R4: 1k; R_0402_1005Metric; LCSC PN C11702
R5, R25: 100k; R_0402_1005Metric; LCSC PN C25741
R6: 10.5k; R_0402_1005Metric; LCSC PN C25850
R7: 10; R_0402_1005Metric; LCSC PN C25077
R8, R9, R10, R11, R12, R13, R14, R16, R17, R84: 10k; R_0402_1005Metric; LCSC PN C25744
R15, R24, R33: 3.3k; R_0402_1005Metric; LCSC PN C25890
R18: 510k; R_0402_1005Metric; LCSC PN C100463
R19: 91k; R_0402_1005Metric; LCSC PN C284722
R20, R21, R22, R23: 4.7k; R_0402_1005Metric; LCSC PN C25900
R26: 115k; R_0603_1608Metric; LCSC PN C227555
R27, R30, R32, R35: 10k; R_0603_1608Metric; LCSC PN C98220
R28: 732k; R_0402_1005Metric; LCSC PN C27016
R29: 34.8k; R_0603_1608Metric; LCSC PN C23141
R31: 20k; R_0603_1608Metric; LCSC PN C4184
R34: 42.2k; R_0603_1608Metric; LCSC PN C227896
R36: 51.1k; C_0603_1608Metric; LCSC PN C23072
R73: 0; R_0603_1608Metric; LCSC PN C21189
SW1, SW2, SW3: PTS645VK31LFS; LCSC PN C2804591
TP1, TP2: TestPoint; TestPoint_Pad_1.5x1.5mm
U1: SRV05-4; SOT-23-6; LCSC PN C13612
U2: CP2102N-A02-GQFN28; QFN-28-1EP_5x5mm_P0.5mm_EP3.35x3.35mm; LCSC PN C964632
U3: HUSB238_002DD; WDFN-10-1EP_3x3mm_P0.5mm_EP1.8x2.5mm; LCSC PN C7471904
U4: TPS22918DBVR; SOT-23-6; LCSC PN C131941
U5: BQ25601; Texas_RTW_WQFN-24-1EP_4x4mm_P0.5mm_EP2.7x2.7mm_ThermalVias; LCSC PN C468236
U6: DFPlayer_mini
U7: DS3231MZ; SOIC-8_3.9x4.9mm_P1.27mm; LCSC PN C107410
U8: TPS63802; VSON-10-HR-DLA; LCSC PN C2845237
U9: NCH2800HV; NCH8200HV
U10: TPS61022; Texas_RWU0007A_VQFN-7_2x2mm_P0.5mm; LCSC PN C2071784
U11: ESP32-S3-WROOM1; ESP32-S3-WROOM-1; LCSC PN C2913198
U12: TPS2121; Texas_VQFN-HR-12_2x2.5mm_P0.5mm_ThermalVias; LCSC PN C2156025
U13: TPS22810DBVR; SOT-23-6; LCSC PN C205990

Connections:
5V_MODE: U10.6 (MODE), U11.28 (IO35)
+3V3: C2.1, C8.1, C16.1, C17.1, C18.1, J3.2, R3.2, R16.1, R17.1, R18.1, R20.2, R21.1, R22.2, R23.2, R24.2, U2.6 (VDD), U2.7 (VREGIN), U7.2 (VCC), U8.6 (VOUT), U11.2 (3V3)
+5V: C4.1, C20.1, J3.9, R1.2, R28.1, R31.1, R33.2, R34.1, R84.2, U4.1 (VIN), U10.3 (VOUT), U12.2 (IN2); also elsewhere on the board
/Gasgauge/CHG: C11.1, U5.13 (BAT), U5.14 (BAT); also elsewhere on the board
/HV_boost/PWR_HV+: U9.3 (Vout); also elsewhere on the board
/HV_boost/PWR_VIN+: R73.2; also elsewhere on the board
/nixie_anode_mux/T0: U11.17 (IO9); also elsewhere on the board
/nixie_anode_mux/T0_E: J4.2; also elsewhere on the board
/nixie_anode_mux/T1: U11.18 (IO10); also elsewhere on the board
/nixie_anode_mux/T1_E: J4.4; also elsewhere on the board
/nixie_anode_mux/T2: U11.19 (IO11); also elsewhere on the board
/nixie_anode_mux/T2_E: J4.6; also elsewhere on the board
/nixie_anode_mux/T3_E: J4.8; also elsewhere on the board
/nixie_anode_mux/T4_E: J4.10; also elsewhere on the board
/nixie_anode_mux/T5_E: J4.9; also elsewhere on the board
/nixie_anode_mux/T6_E: J4.7; also elsewhere on the board
/nixie_anode_mux/T7_E: J4.5; also elsewhere on the board
AGND1: C6.2, C10.2, NT1.1, R9.2, R13.2
BAT_LOW: U11.15 (IO3); also elsewhere on the board
BTN_0: SW1.2, U11.12 (IO8)
BTN_1: SW2.2, U11.20 (IO12)
BTN_2: SW3.2, U11.21 (IO13)
CHIP_PU: C14.1, Q2.3 (C), R17.2, U11.3 (EN)
DF_EN: U4.3 (ON), U11.9 (IO16)
DISPLAY_TYPE: J4.1, U11.13 (IO19)
DTR: Q3.2 (E), R11.2, U2.28 (~DTR)
GND: C1.2, C2.2, C4.2, C7.2, C8.2, C14.2, C17.2, C18.2, J3.10, NT2.1, R2.2, R4.1, SW1.1, SW2.1, SW3.1, U2.3 (GND), U2.29 (GND), U4.2 (GND), U6.7 (GND), U6.10 (GND), U7.5 (GND), U11.1 (GND1), U11.40 (GND2), U11.41 (EPAD)
GPIO0: Q3.3 (C), U11.27 (IO0)
HV_EN: U11.8 (IO15), U13.3 (ON)
HV_PWR+: R73.1, U9.1 (Vin), U13.4 (VOUT)
I2C0_SCL: J3.3, R22.1, U5.5 (SCL), U11.5 (IO5); also elsewhere on the board
I2C0_SDA: J3.1, R23.1, U5.6 (SDA), U11.6 (IO6); also elsewhere on the board
I2C1_SCL: J3.7, R20.1, U7.8 (SCL), U11.10 (IO17)
I2C1_SDA: J3.5, R21.2, U7.7 (SDA), U11.11 (IO18)
unnamed: C9.1, L1.1, U5.19 (SW), U5.20 (SW)
unnamed: D1.2 (A), R15.2
unnamed: D1.1 (K), U5.3 (~PG)
unnamed: D2.2 (A), R24.1
unnamed: D3.2 (A), R33.1
unnamed: J1.A5 (CC1), U1.3 (IO2), U3.4 (CC1)
unnamed: J1.B5 (CC2), U1.4 (IO3), U3.5 (CC2)
unnamed: Q1.4 (G), R7.1
unnamed: C3.1, J1.A4 (VBUS), J1.A9 (VBUS), J1.B4 (VBUS), J1.B9 (VBUS), Q1.1 (S), R5.1, U1.5 (VP), U3.1 (VIN)
unnamed: Q2.1 (B), R11.1
unnamed: Q3.1 (B), R10.1
unnamed: C1.1, R1.1, R2.1, U2.8 (VBUS)
unnamed: R3.1, U2.9 (~RST)
unnamed: R4.2, U2.11 (~SUSPEND)
unnamed: R5.2, R7.2, U3.10 (GATE)
unnamed: R6.1, U3.9 (ISET)
unnamed: R8.1, U3.8 (VSET)
unnamed: C7.1, U4.6 (CT)
unnamed: U4.4 (VOUT), U6.1 (Vcc)
unnamed: C9.2, U5.21 (BTST)
unnamed: C6.1, U5.23 (PMID)
unnamed: R9.1, U5.2 (PSEL), U5.9 (~CE)
unnamed: C10.1, R12.1, U5.22 (REGN)
unnamed: R14.2, U5.4 (STAT)
unnamed: R12.2, R13.1, U5.11 (TS)
unnamed: LS1.2, U6.6 (SPK_1)
unnamed: LS1.1, U6.8 (SPK_2)
unnamed: R18.2, R19.1, U8.4 (FB)
unnamed: L2.1, U8.9 (L1)
unnamed: L2.2, U8.7 (L2)
unnamed: R25.1, R28.2, U10.4 (FB)
unnamed: L3.2, U10.2 (SW)
unnamed: TP2.1, U11.31 (IO38)
unnamed: TP1.1, U11.32 (IO39)
unnamed: R31.2, R32.1, U12.3 (CP2)
unnamed: R36.1, U12.10 (ILIM)
unnamed: R26.2, R27.1, U12.5 (OV1)
unnamed: R34.2, R35.1, U12.4 (OV2)
unnamed: R29.2, R30.1, U12.6 (PR1)
unnamed: C22.1, U12.11 (SS)
unnamed: C23.1, U13.6 (CT)
unnamed: U12.1 (OUT), U12.8 (OUT), U13.1 (VIN)
PGND1: C3.2, C5.2, C11.2, C12.2, C13.2, C15.2, C16.2, C19.2, C20.2, C22.2, C23.2, D2.1 (K), D3.1 (K), J1.A1 (GND), J1.A12 (GND), J1.B1 (GND), J1.B12 (GND), J1.S1 (SHIELD), J2.2, J4.3, NT1.2, NT2.2, R6.2, R8.2, R19.2, R25.2, R27.2, R30.2, R32.2, R35.2, R36.2, U1.2 (VN), U3.11 (GND), U5.17 (GND), U5.18 (GND), U5.25 (GND), U8.3 (AGND), U8.8 (GND), U9.2 (GND), U9.4 (GND), U10.1 (GND), U12.12 (GND), U13.2 (GND); also elsewhere on the board
RGB_LED_DI: J3.6, U11.7 (IO7)
RTS: Q2.2 (E), R10.2, U2.24 (~RTS)
U0RXD: U2.26 (TXD), U11.36 (RXD0)
U0TXD: U2.25 (RXD), U11.37 (TXD0)
U1RXD: U6.2 (RX), U11.35 (IO42)
U1TXD: U6.3 (TX), U11.34 (IO41)
USB_D+: J1.A6 (D+), J1.B6 (D+), U1.1 (IO1), U2.4 (D+), U3.2 (D+)
USB_D-: J1.A7 (D-), J1.B7 (D-), U1.6 (IO4), U2.5 (D-), U3.3 (D-)
VBAT: J2.1, U7.6 (VBAT); also elsewhere on the board
VBUS: C5.1, C19.1, Q1.5 (D), R26.1, R29.1, U5.1 (VAC), U5.24 (VBUS), U12.7 (IN1)
VIN_ST: R84.1, U11.14 (IO20), U12.9 (ST)
VSYS: C12.1, C13.1, C15.1, L1.2, L3.1, R14.1, R15.1, U5.15 (SYS), U5.16 (SYS), U8.1 (EN), U8.2 (MODE), U8.10 (VIN), U10.5 (EN), U10.7 (VIN)
~NIXIE_OE: J3.4, U11.4 (IO4)
~RTC_INT: R16.2, U7.3 (~INT/SQW), U11.38 (IO2)

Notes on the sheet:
optional USB to UART normal open, debug purpose
PSEL charging current sel 500mA pull high 2.1A pull low
VSYS=2.7~4.2V from battery
RVSET(kΩ) - VSET 0 - 5 6.04 - 9 10 - 12 14 - 15 17.8 - 18 Open - 20
DISPLAY TYPE 0V IN-4 1.65V IN-14(8pcs) 3.3V IN-14
Auto program ---------------------- DTR RTS -> EN IO0 IO2 1 1 1 1 1 0 0 1 1 1 1 0 0 1 1 0 1 1 0 0
Reference: https://dl.espressif.com/dl/schematics/SCH_ESP32-S3-DevKitC-1_V1.1_20220413.pdf
XH2.54mm socket 3W max
USB to UART connect default connect to CP2102
RISET(kΩ)-ISET_CURERNT 0 - 1.25 4.53 - 1.5 7.5 - 1.75 10.5 - 2 13.7 - 2.25 16.5 - 2.5 19.6 - 2.75 22.6 - 3 Open - 3.25
baud 9600, databits=1
5v mode 0:PFM 1:PWM
Vertical type C connector
XH2.54 female socket
PCA9685 address: 0x40-0x43
OV1=13.25v PR1=7.47v CP2=1.67v OV2=5.53v ILIM=1.94A
RTC circuit, directly connect VBAT to Lipo battery since there should be UVLO protection on battery Address: 0x68
VBUS=5~12V from USB

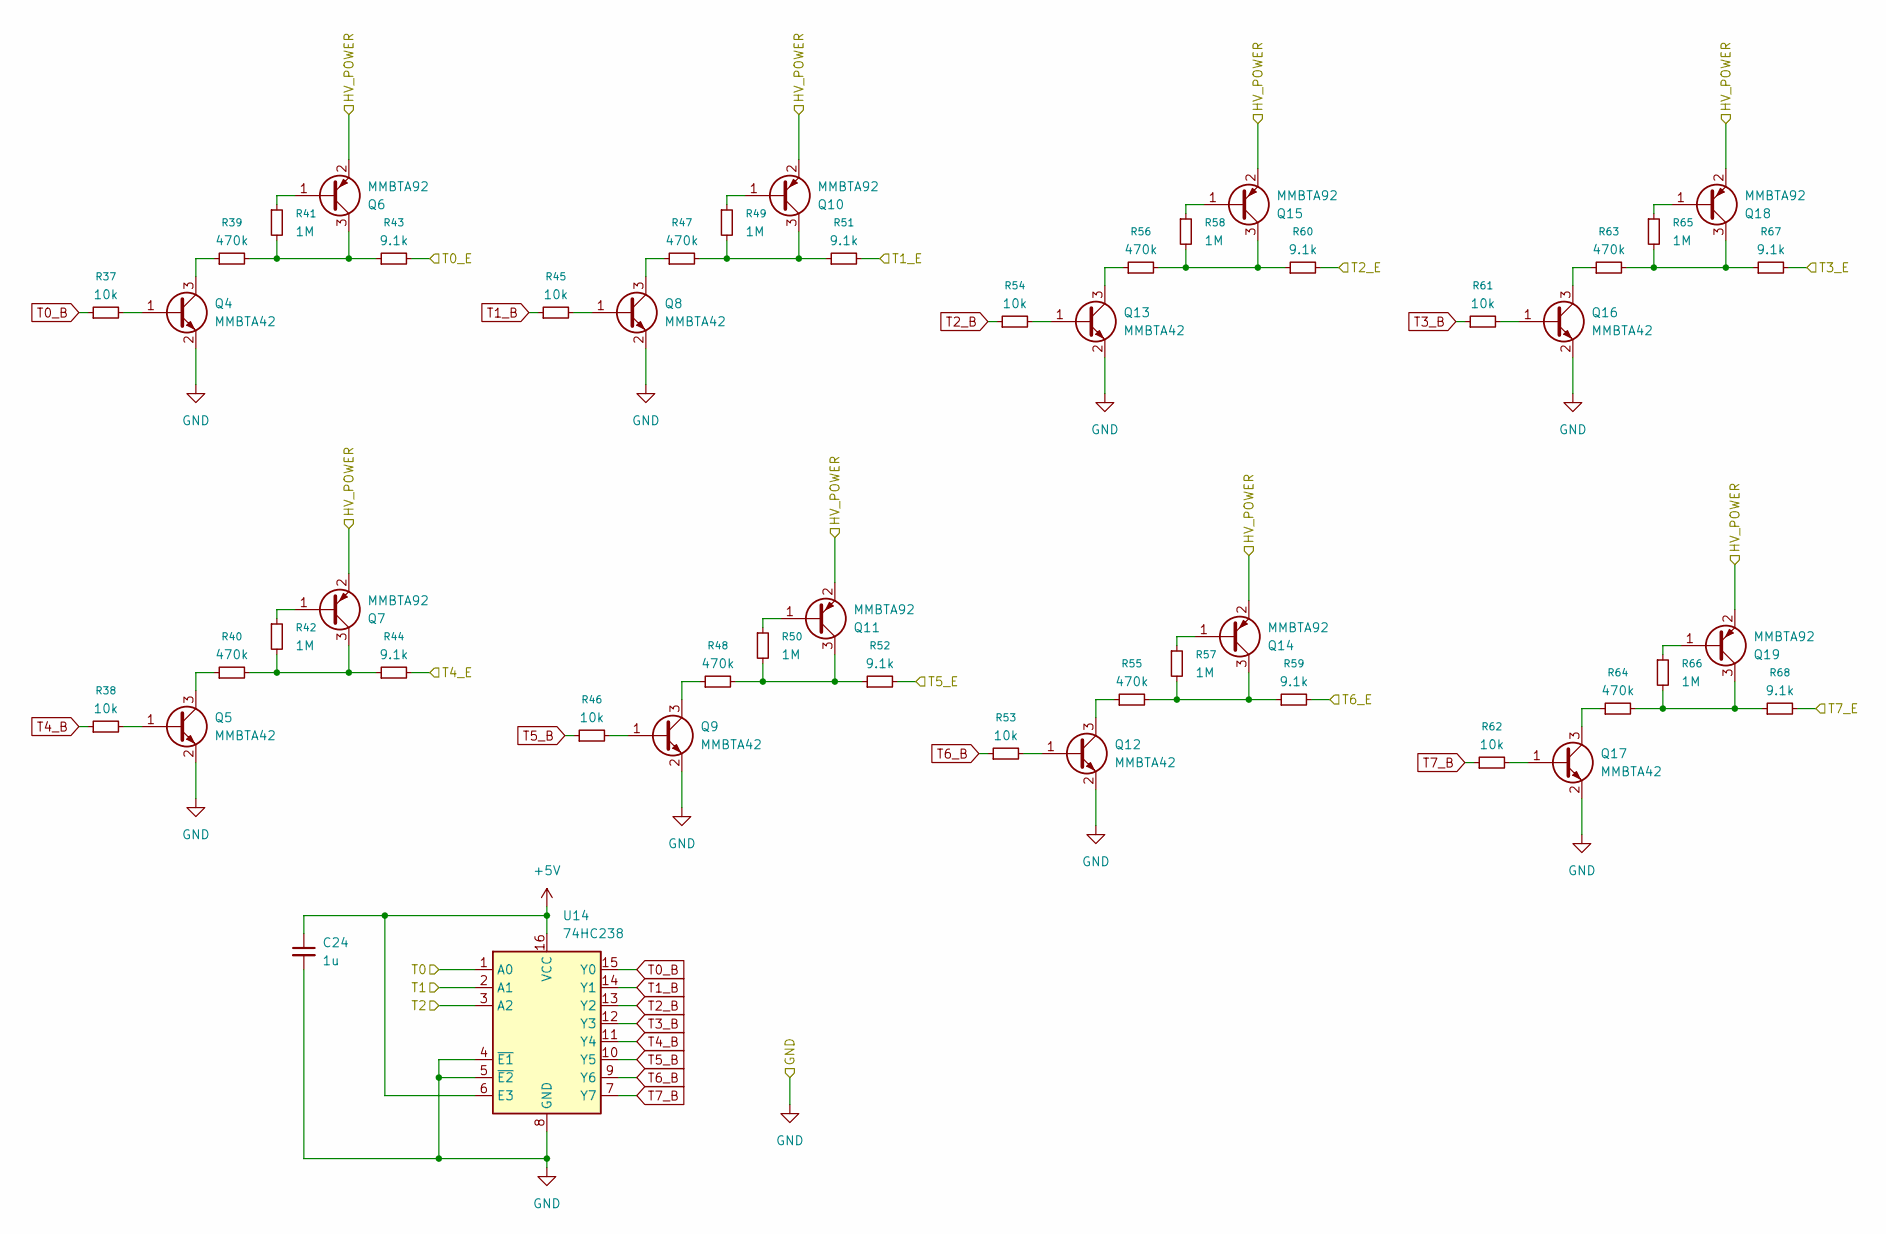
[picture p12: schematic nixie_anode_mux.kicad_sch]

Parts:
C24: 1u; C_0603_1608Metric; LCSC PN C5199872
Q4, Q5, Q8, Q9, Q12, Q13, Q16, Q17: MMBTA42; SOT-23; LCSC PN C94389
Q6, Q7, Q10, Q11, Q14, Q15, Q18, Q19: MMBTA92; SOT-23; LCSC PN C82049
R37, R38, R45, R46, R53, R54, R61, R62: 10k; R_0402_1005Metric; LCSC PN C25744
R39, R40, R47, R48, R55, R56, R63, R64: 470k; R_0402_1005Metric; LCSC PN C100446
R41, R42, R49, R50, R57, R58, R65, R66: 1M; R_0402_1005Metric; LCSC PN C26083
R43, R44, R51, R52, R59, R60, R67, R68: 9.1k; R_0402_1005Metric; LCSC PN C100555
U14: 74HC238; DHVQFN-16-1EP_2.5x3.5mm_P0.5mm_EP1x2mm; LCSC PN C546729

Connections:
+5V: C24.1, U14.6 (E3), U14.16 (VCC); also elsewhere on the board
/HV_boost/PWR_HV+: Q6.2 (E), Q7.2 (E), Q10.2 (E), Q11.2 (E), Q14.2 (E), Q15.2 (E), Q18.2 (E), Q19.2 (E); also elsewhere on the board
/nixie_anode_mux/T0: U14.1 (A0); also elsewhere on the board
/nixie_anode_mux/T0_E: R43.2; also elsewhere on the board
/nixie_anode_mux/T1: U14.2 (A1); also elsewhere on the board
/nixie_anode_mux/T1_E: R51.2; also elsewhere on the board
/nixie_anode_mux/T2: U14.3 (A2); also elsewhere on the board
/nixie_anode_mux/T2_E: R60.2; also elsewhere on the board
/nixie_anode_mux/T3_E: R67.2; also elsewhere on the board
/nixie_anode_mux/T4_E: R44.2; also elsewhere on the board
/nixie_anode_mux/T5_E: R52.2; also elsewhere on the board
/nixie_anode_mux/T6_E: R59.2; also elsewhere on the board
/nixie_anode_mux/T7_E: R68.2; also elsewhere on the board
unnamed: Q4.1 (B), R37.2
unnamed: Q4.3 (C), R39.1
unnamed: Q5.1 (B), R38.2
unnamed: Q5.3 (C), R40.1
unnamed: Q6.1 (B), R41.1
unnamed: Q6.3 (C), R39.2, R41.2, R43.1
unnamed: Q7.1 (B), R42.1
unnamed: Q7.3 (C), R40.2, R42.2, R44.1
unnamed: Q8.1 (B), R45.2
unnamed: Q8.3 (C), R47.1
unnamed: Q9.1 (B), R46.2
unnamed: Q9.3 (C), R48.1
unnamed: Q10.1 (B), R49.1
unnamed: Q10.3 (C), R47.2, R49.2, R51.1
unnamed: Q11.1 (B), R50.1
unnamed: Q11.3 (C), R48.2, R50.2, R52.1
unnamed: Q12.1 (B), R53.2
unnamed: Q12.3 (C), R55.1
unnamed: Q13.1 (B), R54.2
unnamed: Q13.3 (C), R56.1
unnamed: Q14.1 (B), R57.1
unnamed: Q14.3 (C), R55.2, R57.2, R59.1
unnamed: Q15.1 (B), R58.1
unnamed: Q15.3 (C), R56.2, R58.2, R60.1
unnamed: Q16.1 (B), R61.2
unnamed: Q16.3 (C), R63.1
unnamed: Q17.1 (B), R62.2
unnamed: Q17.3 (C), R64.1
unnamed: Q18.1 (B), R65.1
unnamed: Q18.3 (C), R63.2, R65.2, R67.1
unnamed: Q19.1 (B), R66.1
unnamed: Q19.3 (C), R64.2, R66.2, R68.1
PGND1: C24.2, Q4.2 (E), Q5.2 (E), Q8.2 (E), Q9.2 (E), Q12.2 (E), Q13.2 (E), Q16.2 (E), Q17.2 (E), U14.4 (~E1), U14.5 (~E2), U14.8 (GND); also elsewhere on the board
T0_B: R37.1, U14.15 (Y0)
T1_B: R45.1, U14.14 (Y1)
T2_B: R54.1, U14.13 (Y2)
T3_B: R61.1, U14.12 (Y3)
T4_B: R38.1, U14.11 (Y4)
T5_B: R46.1, U14.10 (Y5)
T6_B: R53.1, U14.9 (Y6)
T7_B: R62.1, U14.7 (Y7)

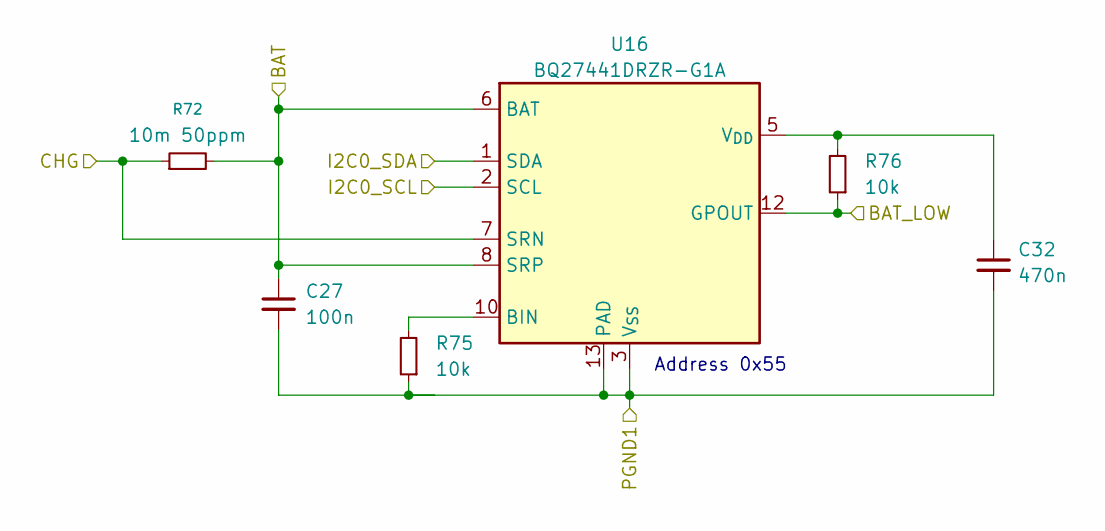
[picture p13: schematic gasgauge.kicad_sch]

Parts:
C27: 100n; C_0402_1005Metric; LCSC PN C1525
C32: 470n; C_0603_1608Metric; LCSC PN C1623
R72: 10m 50ppm; R_0805_2012Metric; LCSC PN C201254
R75, R76: 10k; R_0402_1005Metric; LCSC PN C25744
U16: BQ27441DRZR-G1A; Texas_S-PDSO-N12; LCSC PN C473397

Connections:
/Gasgauge/CHG: R72.1, U16.7 (SRN); also elsewhere on the board
BAT_LOW: R76.1, U16.12 (GPOUT); also elsewhere on the board
I2C0_SCL: U16.2 (SCL); also elsewhere on the board
I2C0_SDA: U16.1 (SDA); also elsewhere on the board
unnamed: R75.2, U16.10 (BIN)
unnamed: C32.1, R76.2, U16.5 (V_{DD})
PGND1: C27.2, C32.2, R75.1, U16.3 (V_{SS}), U16.13 (PAD); also elsewhere on the board
VBAT: C27.1, R72.2, U16.6 (BAT), U16.8 (SRP); also elsewhere on the board

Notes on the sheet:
Address 0x55

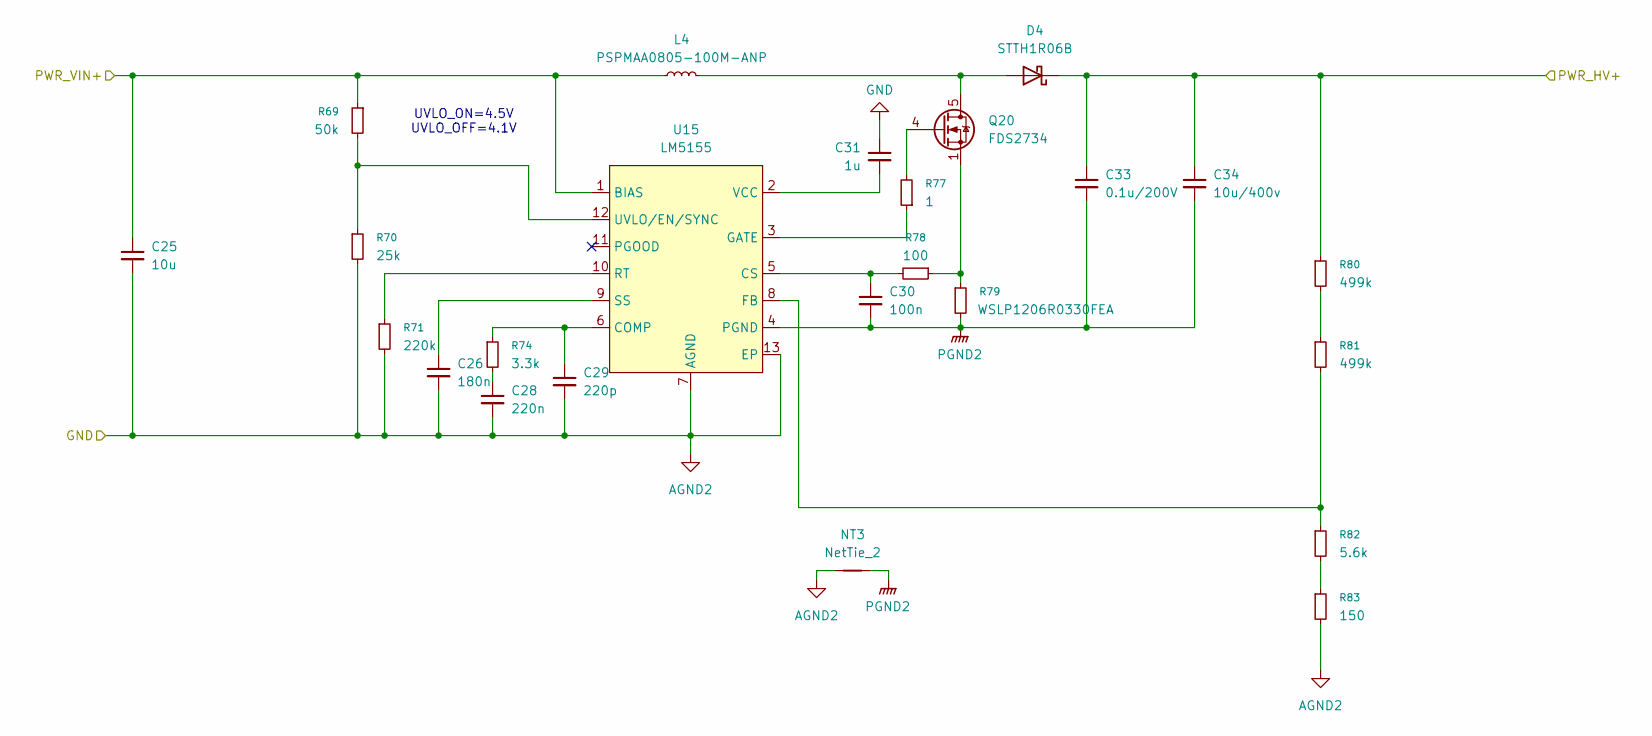
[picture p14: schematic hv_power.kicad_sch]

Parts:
C25: 10u; C_0805_2012Metric; LCSC PN C6119932
C26: 180n; C_0402_1005Metric; LCSC PN C309457
C28: 220n; C_0402_1005Metric; LCSC PN C16772
C29: 220p; C_0402_1005Metric; LCSC PN C1530
C30: 100n; C_0402_1005Metric; LCSC PN C1525
C31: 1u; C_0603_1608Metric; LCSC PN C5199872
C33: 0.1u/200V; C_1206_3216Metric; LCSC PN C113894
C34: 10u/400v; Cap_THT_D8.0mm_L12mm_Horizontal; LCSC PN C46867081
D4: STTH1R06B; D_SMB; LCSC PN C283526
L4: PSPMAA0805-100M-ANP; PowerInductor_8mmx8.5mm; LCSC PN C2962885
NT3: NetTie_2; NetTie-2_SMD_Pad0.5mm
Q20: FDS2734; SOIC-8_3.9x4.9mm_P1.27mm; LCSC PN C606022
R69: 50k; R_0402_1005Metric; LCSC PN C166559
R70: 25k; R_0402_1005Metric; LCSC PN C2766803
R71: 220k; R_0402_1005Metric; LCSC PN C25546
R74: 3.3k; R_0402_1005Metric; LCSC PN C25890
R77: 1; R_0402_1005Metric; LCSC PN C25086
R78: 100; R_0402_1005Metric; LCSC PN C25076
R79: WSLP1206R0330FEA; R_1206_3216Metric; LCSC PN C2084257
R80, R81: 499k; R_0402_1005Metric; LCSC PN C25793
R82: 5.6k; R_0402_1005Metric; LCSC PN C881140
R83: 150; R_0402_1005Metric; LCSC PN C25082
U15: LM5155; WSON-12-1EP_3x2mm_P0.5mm_EP1x2.65; LCSC PN C545416

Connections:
/HV_boost/PWR_HV+: C33.1, C34.1, D4.1 (K), R80.1; also elsewhere on the board
/HV_boost/PWR_VIN+: C25.1, L4.1, R69.1, U15.1 (BIAS); also elsewhere on the board
unnamed: C28.1, R74.2
unnamed: D4.2 (A), L4.2, Q20.5 (D), Q20.6 (D), Q20.7 (D), Q20.8 (D)
unnamed: Q20.4 (G), R77.2
unnamed: Q20.1 (S), Q20.2 (S), Q20.3 (S), R78.1, R79.1
unnamed: R80.2, R81.1
unnamed: R82.2, R83.1
unnamed: C29.1, R74.1, U15.6 (COMP)
unnamed: C30.1, R78.2, U15.5 (CS)
unnamed: R81.2, R82.1, U15.8 (FB)
unnamed: R77.1, U15.3 (GATE)
unnamed: R71.1, U15.10 (RT)
unnamed: C26.1, U15.9 (SS)
unnamed: R69.2, R70.1, U15.12 (UVLO/EN/SYNC)
unnamed: C31.2, U15.2 (VCC)
PGND1: C25.2, C26.2, C28.2, C29.2, C31.1, NT3.1, R70.2, R71.2, R83.2, U15.7 (AGND), U15.13 (EP); also elsewhere on the board
PGND2: C30.2, C33.2, C34.2, NT3.2, R79.2, U15.4 (PGND)

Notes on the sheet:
UVLO_ON=4.5V UVLO_OFF=4.1V

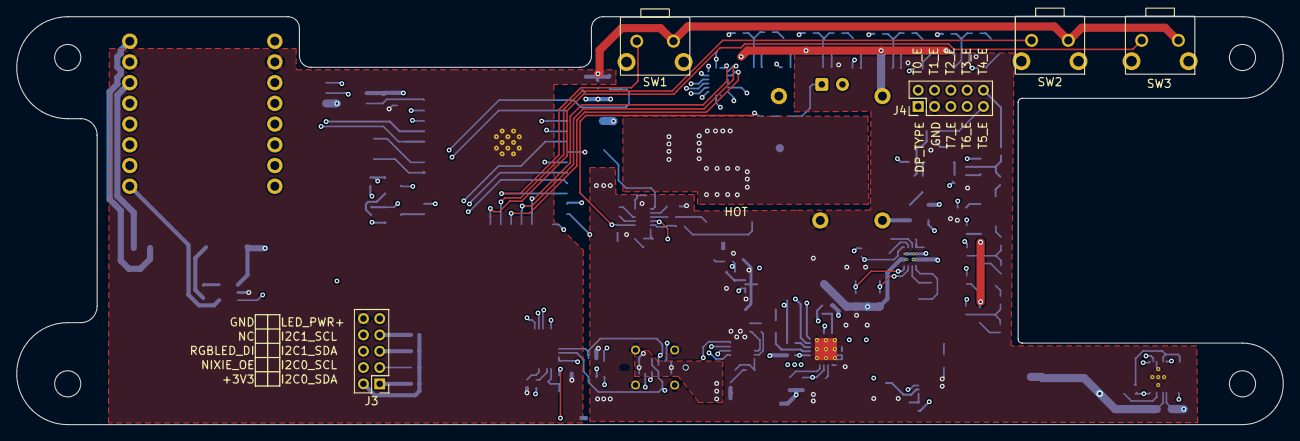
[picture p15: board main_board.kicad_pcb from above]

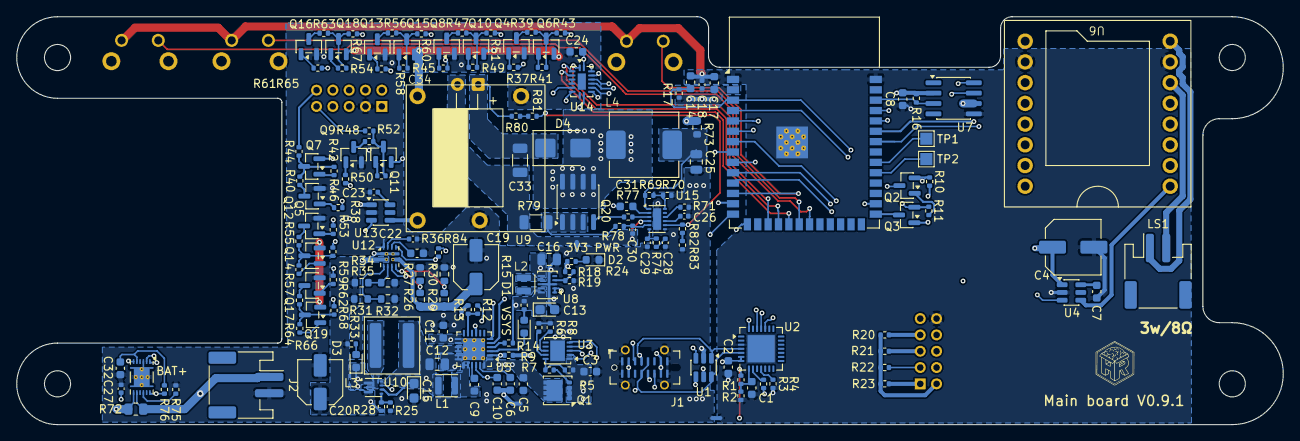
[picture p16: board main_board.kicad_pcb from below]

Board: 4 copper layers, 155.2 x 50.0 mm, 178 parts (169 on the bottom side), 148 nets.

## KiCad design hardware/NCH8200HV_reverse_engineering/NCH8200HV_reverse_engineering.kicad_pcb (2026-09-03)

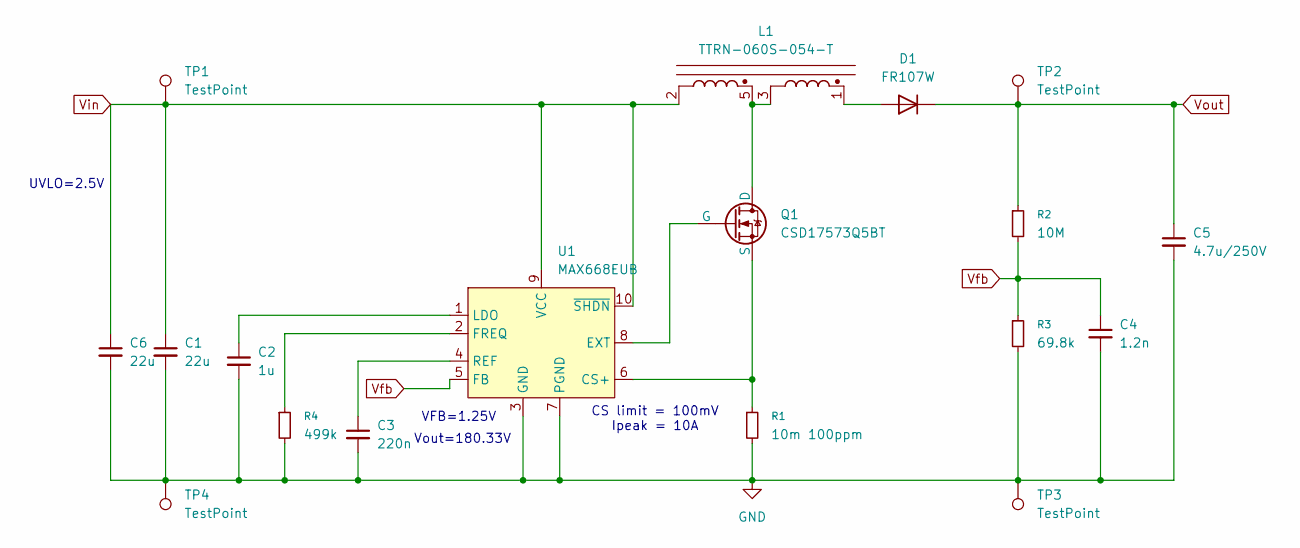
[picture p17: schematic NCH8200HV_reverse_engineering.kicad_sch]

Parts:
C1, C6: 22u; C_0805_2012Metric; LCSC PN C45783
C2: 1u; C_0603_1608Metric; LCSC PN C15849
C3: 220n; C_0603_1608Metric; LCSC PN C21120
C4: 1.2n; C_0603_1608Metric; LCSC PN C68659
C5: 4.7u/250V; C_Elec_8x10.2; LCSC PN C88691
D1: FR107W; D_SOD-123F; LCSC PN C108820
L1: TTRN-060S-054-T; EFD6.5_Transformer
Q1: CSD17573Q5BT; PQFN-8-EP_6x5mm_P1.27mm_Generic; LCSC PN C2868471
R1: 10m 100ppm; R_0805_2012Metric; LCSC PN C723457
R2: 10M; R_0603_1608Metric; LCSC PN C7250
R3: 69.8k; R_0603_1608Metric; LCSC PN C23098
R4: 499k; R_0603_1608Metric; LCSC PN C26751
TP1, TP2, TP3, TP4: TestPoint; TestPoint_THTPad_D2.0mm_Drill1.0mm
U1: MAX668EUB; MSOP-10_3x3mm_P0.5mm; LCSC PN C143564

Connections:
GND: C1.2, C2.2, C3.2, C4.2, C5.2, C6.2, R1.2, R3.2, R4.2, TP3.1, TP4.1, U1.3 (GND), U1.7 (PGND)
unnamed: D1.2 (A), L1.1
unnamed: L1.3, L1.5, Q1.5 (D)
unnamed: Q1.4 (G), U1.8 (EXT)
unnamed: Q1.1 (S), R1.1, U1.6 (CS+)
unnamed: R4.1, U1.2 (FREQ)
unnamed: C2.1, U1.1 (LDO)
unnamed: C3.1, U1.4 (REF)
Vfb: C4.1, R2.2, R3.1, U1.5 (FB)
Vin: C1.1, C6.1, L1.2, TP1.1, U1.9 (VCC), U1.10 (~SHDN)
Vout: C5.1, D1.1 (K), R2.1, TP2.1

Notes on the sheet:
UVLO=2.5V
VFB=1.25V
CS limit = 100mV Ipeak = 10A
Vout=180.33V

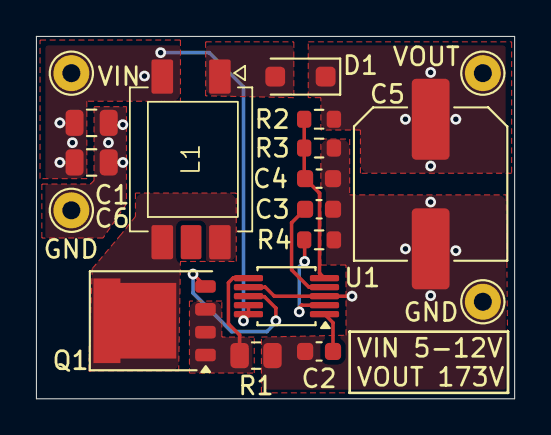
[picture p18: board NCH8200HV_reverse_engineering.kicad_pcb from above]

Board: 2 copper layers, 26.6 x 20.1 mm, 18 parts (0 on the bottom side), 11 nets.

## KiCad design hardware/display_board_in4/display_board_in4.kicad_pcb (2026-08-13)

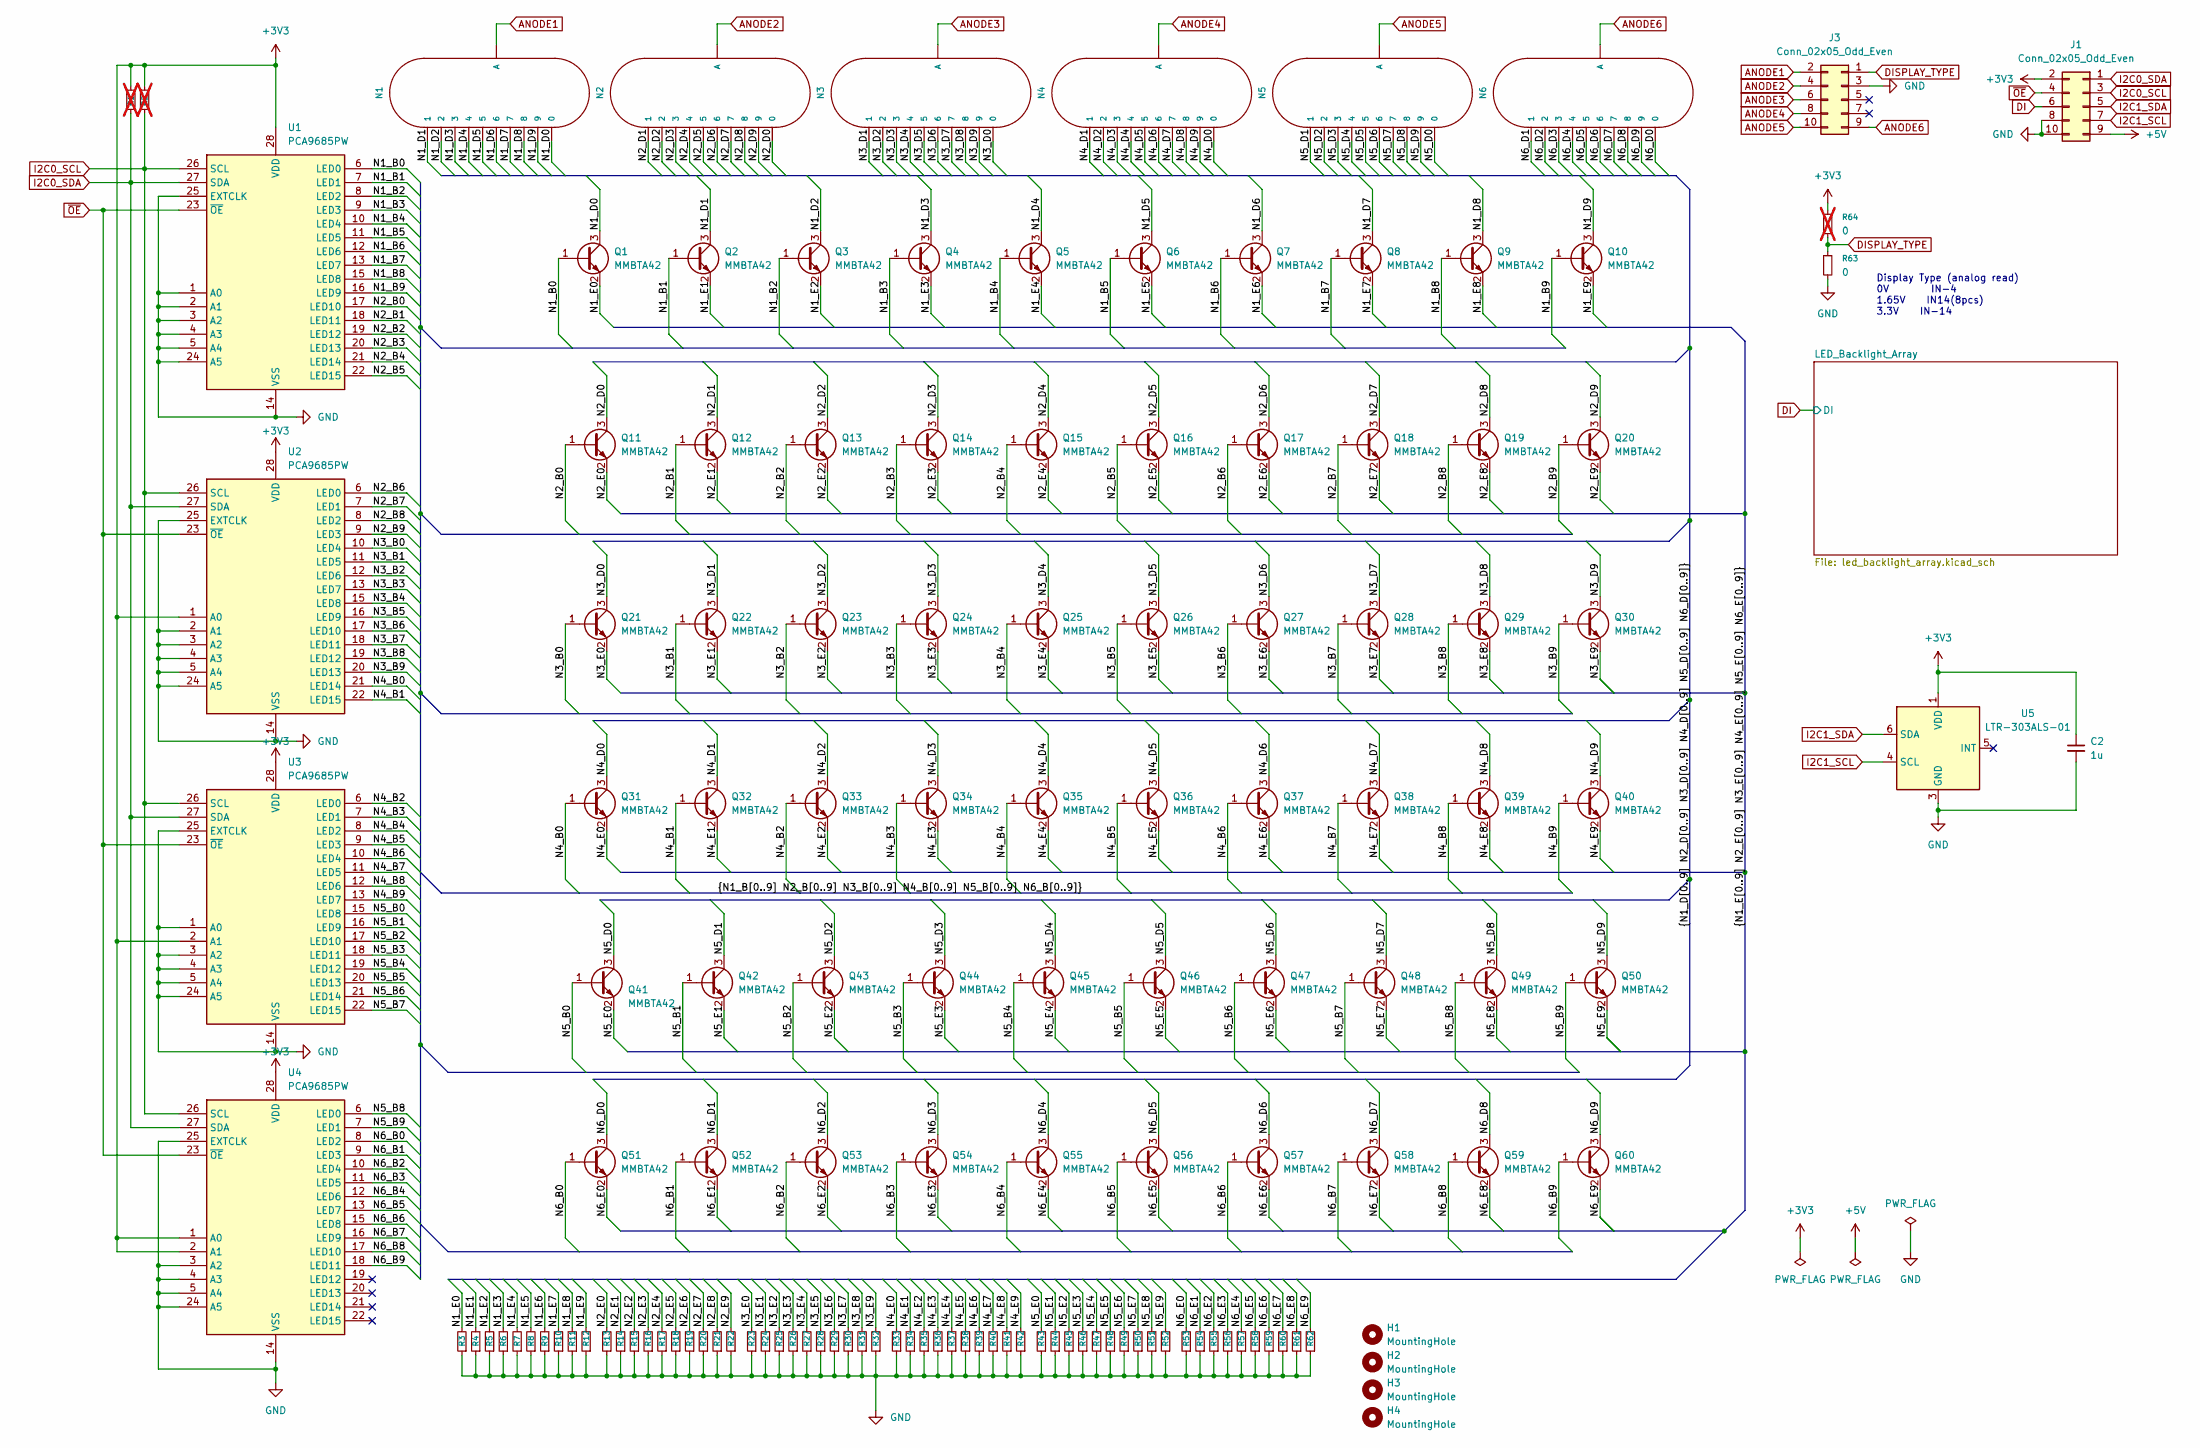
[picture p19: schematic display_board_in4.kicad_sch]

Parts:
C2: 1u; C_0603_1608Metric; LCSC PN C15849
H1, H2, H3, H4: MountingHole; MountingHole_3.2mm_M3_DIN965
J1, J3: Conn_02x05_Odd_Even; PinSocket_2x05_P2.00mm_Vertical_SMD; LCSC PN C22373873
N1, N2, N3, N4, N5, N6: IN-4; nixies-us-IN-4-DSUB
Q1, Q2, Q3, Q4, Q5, Q6, Q7, Q8, Q9, Q10, Q11, Q12, Q13, Q14, Q15, Q16, Q17, Q18, Q19, Q20, Q21, Q22, Q23, Q24, Q25, Q26, Q27, Q28, Q29, Q30, Q31, Q32, Q33, Q34, Q35, Q36, Q37, Q38, Q39, Q40, Q41, Q42, Q43, Q44, Q45, Q46, Q47, Q48, Q49, Q50, Q51, Q52, Q53, Q54, Q55, Q56, Q57, Q58, Q59, Q60: MMBTA42; SOT-23; LCSC PN C94389
R1, R2: 2.2k; R_0603_1608Metric; LCSC PN C4190; not fitted
R3, R4, R5, R6, R7, R8, R9, R10, R11, R12, R13, R14, R15, R16, R17, R18, R19, R20, R21, R22, R23, R24, R25, R26, R27, R28, R29, R30, R31, R32, R33, R34, R35, R36, R37, R38, R39, R40, R41, R42, R43, R44, R45, R46, R47, R48, R49, R50, R51, R52, R53, R54, R55, R56, R57, R58, R59, R60, R61, R62: 1k; R_0603_1608Metric; LCSC PN C21190
R63: 0; R_0603_1608Metric; LCSC PN C21189
R64: 0; R_0603_1608Metric; not fitted
U1, U2, U3, U4: PCA9685PW; TSSOP-28_4.4x9.7mm_P0.65mm; LCSC PN C2678753
U5: LTR-303ALS-01; Lite-On_LTR-303ALS-01; LCSC PN C364577

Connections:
+3V3: C2.1, J1.2, R1.1, R2.1, R64.1, U1.28 (VDD), U2.1 (A0), U2.28 (VDD), U3.2 (A1), U3.28 (VDD), U4.1 (A0), U4.2 (A1), U4.28 (VDD), U5.1 (VDD)
+5V: J1.9; also elsewhere on the board
/N1_B0: Q1.1 (B), U1.6 (LED0)
/N1_B1: Q2.1 (B), U1.7 (LED1)
/N1_B2: Q3.1 (B), U1.8 (LED2)
/N1_B3: Q4.1 (B), U1.9 (LED3)
/N1_B4: Q5.1 (B), U1.10 (LED4)
/N1_B5: Q6.1 (B), U1.11 (LED5)
/N1_B6: Q7.1 (B), U1.12 (LED6)
/N1_B7: Q8.1 (B), U1.13 (LED7)
/N1_B8: Q9.1 (B), U1.15 (LED8)
/N1_B9: Q10.1 (B), U1.16 (LED9)
/N1_D0: N1.0, Q1.3 (C)
/N1_D1: N1.1, Q2.3 (C)
/N1_D2: N1.2, Q3.3 (C)
/N1_D3: N1.3, Q4.3 (C)
/N1_D4: N1.4, Q5.3 (C)
/N1_D5: N1.5, Q6.3 (C)
/N1_D6: N1.6, Q7.3 (C)
/N1_D7: N1.7, Q8.3 (C)
/N1_D8: N1.8, Q9.3 (C)
/N1_D9: N1.9, Q10.3 (C)
/N1_E0: Q1.2 (E), R3.2
/N1_E1: Q2.2 (E), R4.2
/N1_E2: Q3.2 (E), R5.2
/N1_E3: Q4.2 (E), R6.2
/N1_E4: Q5.2 (E), R7.2
/N1_E5: Q6.2 (E), R8.2
/N1_E6: Q7.2 (E), R9.2
/N1_E7: Q8.2 (E), R10.2
/N1_E8: Q9.2 (E), R11.2
/N1_E9: Q10.2 (E), R12.2
/N2_B0: Q11.1 (B), U1.17 (LED10)
/N2_B1: Q12.1 (B), U1.18 (LED11)
/N2_B2: Q13.1 (B), U1.19 (LED12)
/N2_B3: Q14.1 (B), U1.20 (LED13)
/N2_B4: Q15.1 (B), U1.21 (LED14)
/N2_B5: Q16.1 (B), U1.22 (LED15)
/N2_B6: Q17.1 (B), U2.6 (LED0)
/N2_B7: Q18.1 (B), U2.7 (LED1)
/N2_B8: Q19.1 (B), U2.8 (LED2)
/N2_B9: Q20.1 (B), U2.9 (LED3)
/N2_D0: N2.0, Q11.3 (C)
/N2_D1: N2.1, Q12.3 (C)
/N2_D2: N2.2, Q13.3 (C)
/N2_D3: N2.3, Q14.3 (C)
/N2_D4: N2.4, Q15.3 (C)
/N2_D5: N2.5, Q16.3 (C)
/N2_D6: N2.6, Q17.3 (C)
/N2_D7: N2.7, Q18.3 (C)
/N2_D8: N2.8, Q19.3 (C)
/N2_D9: N2.9, Q20.3 (C)
/N2_E0: Q11.2 (E), R13.2
/N2_E1: Q12.2 (E), R14.2
/N2_E2: Q13.2 (E), R15.2
/N2_E3: Q14.2 (E), R16.2
/N2_E4: Q15.2 (E), R17.2
/N2_E5: Q16.2 (E), R18.2
/N2_E6: Q17.2 (E), R19.2
/N2_E7: Q18.2 (E), R20.2
/N2_E8: Q19.2 (E), R21.2
/N2_E9: Q20.2 (E), R22.2
/N3_B0: Q21.1 (B), U2.10 (LED4)
/N3_B1: Q22.1 (B), U2.11 (LED5)
/N3_B2: Q23.1 (B), U2.12 (LED6)
/N3_B3: Q24.1 (B), U2.13 (LED7)
/N3_B4: Q25.1 (B), U2.15 (LED8)
/N3_B5: Q26.1 (B), U2.16 (LED9)
/N3_B6: Q27.1 (B), U2.17 (LED10)
/N3_B7: Q28.1 (B), U2.18 (LED11)
/N3_B8: Q29.1 (B), U2.19 (LED12)
/N3_B9: Q30.1 (B), U2.20 (LED13)
/N3_D0: N3.0, Q21.3 (C)
/N3_D1: N3.1, Q22.3 (C)
/N3_D2: N3.2, Q23.3 (C)
/N3_D3: N3.3, Q24.3 (C)
/N3_D4: N3.4, Q25.3 (C)
/N3_D5: N3.5, Q26.3 (C)
/N3_D6: N3.6, Q27.3 (C)
/N3_D7: N3.7, Q28.3 (C)
/N3_D8: N3.8, Q29.3 (C)
/N3_D9: N3.9, Q30.3 (C)
/N3_E0: Q21.2 (E), R23.2
/N3_E1: Q22.2 (E), R24.2
/N3_E2: Q23.2 (E), R25.2
/N3_E3: Q24.2 (E), R26.2
/N3_E4: Q25.2 (E), R27.2
/N3_E5: Q26.2 (E), R28.2
/N3_E6: Q27.2 (E), R29.2
/N3_E7: Q28.2 (E), R30.2
/N3_E8: Q29.2 (E), R31.2
/N3_E9: Q30.2 (E), R32.2
/N4_B0: Q31.1 (B), U2.21 (LED14)
/N4_B1: Q32.1 (B), U2.22 (LED15)
/N4_B2: Q33.1 (B), U3.6 (LED0)
/N4_B3: Q34.1 (B), U3.7 (LED1)
/N4_B4: Q35.1 (B), U3.8 (LED2)
/N4_B5: Q36.1 (B), U3.9 (LED3)
/N4_B6: Q37.1 (B), U3.10 (LED4)
/N4_B7: Q38.1 (B), U3.11 (LED5)
/N4_B8: Q39.1 (B), U3.12 (LED6)
/N4_B9: Q40.1 (B), U3.13 (LED7)
/N4_D0: N4.0, Q31.3 (C)
/N4_D1: N4.1, Q32.3 (C)
/N4_D2: N4.2, Q33.3 (C)
/N4_D3: N4.3, Q34.3 (C)
/N4_D4: N4.4, Q35.3 (C)
/N4_D5: N4.5, Q36.3 (C)
/N4_D6: N4.6, Q37.3 (C)
/N4_D7: N4.7, Q38.3 (C)
/N4_D8: N4.8, Q39.3 (C)
/N4_D9: N4.9, Q40.3 (C)
/N4_E0: Q31.2 (E), R33.2
/N4_E1: Q32.2 (E), R34.2
/N4_E2: Q33.2 (E), R35.2
/N4_E3: Q34.2 (E), R36.2
/N4_E4: Q35.2 (E), R37.2
/N4_E5: Q36.2 (E), R38.2
/N4_E6: Q37.2 (E), R39.2
/N4_E7: Q38.2 (E), R40.2
/N4_E8: Q39.2 (E), R41.2
/N4_E9: Q40.2 (E), R42.2
/N5_B0: Q41.1 (B), U3.15 (LED8)
/N5_B1: Q42.1 (B), U3.16 (LED9)
/N5_B2: Q43.1 (B), U3.17 (LED10)
/N5_B3: Q44.1 (B), U3.18 (LED11)
/N5_B4: Q45.1 (B), U3.19 (LED12)
/N5_B5: Q46.1 (B), U3.20 (LED13)
/N5_B6: Q47.1 (B), U3.21 (LED14)
/N5_B7: Q48.1 (B), U3.22 (LED15)
/N5_B8: Q49.1 (B), U4.6 (LED0)
/N5_B9: Q50.1 (B), U4.7 (LED1)
/N5_D0: N5.0, Q41.3 (C)
/N5_D1: N5.1, Q42.3 (C)
/N5_D2: N5.2, Q43.3 (C)
/N5_D3: N5.3, Q44.3 (C)
/N5_D4: N5.4, Q45.3 (C)
/N5_D5: N5.5, Q46.3 (C)
/N5_D6: N5.6, Q47.3 (C)
/N5_D7: N5.7, Q48.3 (C)
/N5_D8: N5.8, Q49.3 (C)
/N5_D9: N5.9, Q50.3 (C)
/N5_E0: Q41.2 (E), R43.2
/N5_E1: Q42.2 (E), R44.2
/N5_E2: Q43.2 (E), R45.2
/N5_E3: Q44.2 (E), R46.2
/N5_E4: Q45.2 (E), R47.2
/N5_E5: Q46.2 (E), R48.2
/N5_E6: Q47.2 (E), R49.2
/N5_E7: Q48.2 (E), R50.2
/N5_E8: Q49.2 (E), R51.2
/N5_E9: Q50.2 (E), R52.2
/N6_B0: Q51.1 (B), U4.8 (LED2)
/N6_B1: Q52.1 (B), U4.9 (LED3)
/N6_B2: Q53.1 (B), U4.10 (LED4)
/N6_B3: Q54.1 (B), U4.11 (LED5)
/N6_B4: Q55.1 (B), U4.12 (LED6)
/N6_B5: Q56.1 (B), U4.13 (LED7)
/N6_B6: Q57.1 (B), U4.15 (LED8)
/N6_B7: Q58.1 (B), U4.16 (LED9)
/N6_B8: Q59.1 (B), U4.17 (LED10)
/N6_B9: Q60.1 (B), U4.18 (LED11)
/N6_D0: N6.0, Q51.3 (C)
/N6_D1: N6.1, Q52.3 (C)
/N6_D2: N6.2, Q53.3 (C)
/N6_D3: N6.3, Q54.3 (C)
/N6_D4: N6.4, Q55.3 (C)
/N6_D5: N6.5, Q56.3 (C)
/N6_D6: N6.6, Q57.3 (C)
/N6_D7: N6.7, Q58.3 (C)
/N6_D8: N6.8, Q59.3 (C)
/N6_D9: N6.9, Q60.3 (C)
/N6_E0: Q51.2 (E), R53.2
/N6_E1: Q52.2 (E), R54.2
/N6_E2: Q53.2 (E), R55.2
/N6_E3: Q54.2 (E), R56.2
/N6_E4: Q55.2 (E), R57.2
/N6_E5: Q56.2 (E), R58.2
/N6_E6: Q57.2 (E), R59.2
/N6_E7: Q58.2 (E), R60.2
/N6_E8: Q59.2 (E), R61.2
/N6_E9: Q60.2 (E), R62.2
ANODE1: J3.2, N1.A3 (A)
ANODE2: J3.4, N2.A3 (A)
ANODE3: J3.6, N3.A3 (A)
ANODE4: J3.8, N4.A3 (A)
ANODE5: J3.10, N5.A3 (A)
ANODE6: J3.9, N6.A3 (A)
DI: J1.6; also elsewhere on the board
DISPLAY_TYPE: J3.1, R63.1, R64.2
GND: C2.2, J1.8, J1.10, J3.3, R3.1, R4.1, R5.1, R6.1, R7.1, R8.1, R9.1, R10.1, R11.1, R12.1, R13.1, R14.1, R15.1, R16.1, R17.1, R18.1, R19.1, R20.1, R21.1, R22.1, R23.1, R24.1, R25.1, R26.1, R27.1, R28.1, R29.1, R30.1, R31.1, R32.1, R33.1, R34.1, R35.1, R36.1, R37.1, R38.1, R39.1, R40.1, R41.1, R42.1, R43.1, R44.1, R45.1, R46.1, R47.1, R48.1, R49.1, R50.1, R51.1, R52.1, R53.1, R54.1, R55.1, R56.1, R57.1, R58.1, R59.1, R60.1, R61.1, R62.1, R63.2, U1.1 (A0), U1.2 (A1), U1.3 (A2), U1.4 (A3), U1.5 (A4), U1.14 (VSS), U1.24 (A5), U1.25 (EXTCLK), U2.2 (A1), U2.3 (A2), U2.4 (A3), U2.5 (A4), U2.14 (VSS), U2.24 (A5), U2.25 (EXTCLK), U3.1 (A0), U3.3 (A2), U3.4 (A3), U3.5 (A4), U3.14 (VSS), U3.24 (A5), U3.25 (EXTCLK), U4.3 (A2), U4.4 (A3), U4.5 (A4), U4.14 (VSS), U4.24 (A5), U4.25 (EXTCLK), U5.3 (GND); also elsewhere on the board
I2C0_SCL: J1.3, R2.2, U1.26 (SCL), U2.26 (SCL), U3.26 (SCL), U4.26 (SCL)
I2C0_SDA: J1.1, R1.2, U1.27 (SDA), U2.27 (SDA), U3.27 (SDA), U4.27 (SDA)
I2C1_SCL: J1.7, U5.4 (SCL)
I2C1_SDA: J1.5, U5.6 (SDA)
~OE: J1.4, U1.23 (~OE), U2.23 (~OE), U3.23 (~OE), U4.23 (~OE)

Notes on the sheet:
Display Type (analog read) 0V IN-4 1.65V IN14(8pcs) 3.3V IN-14

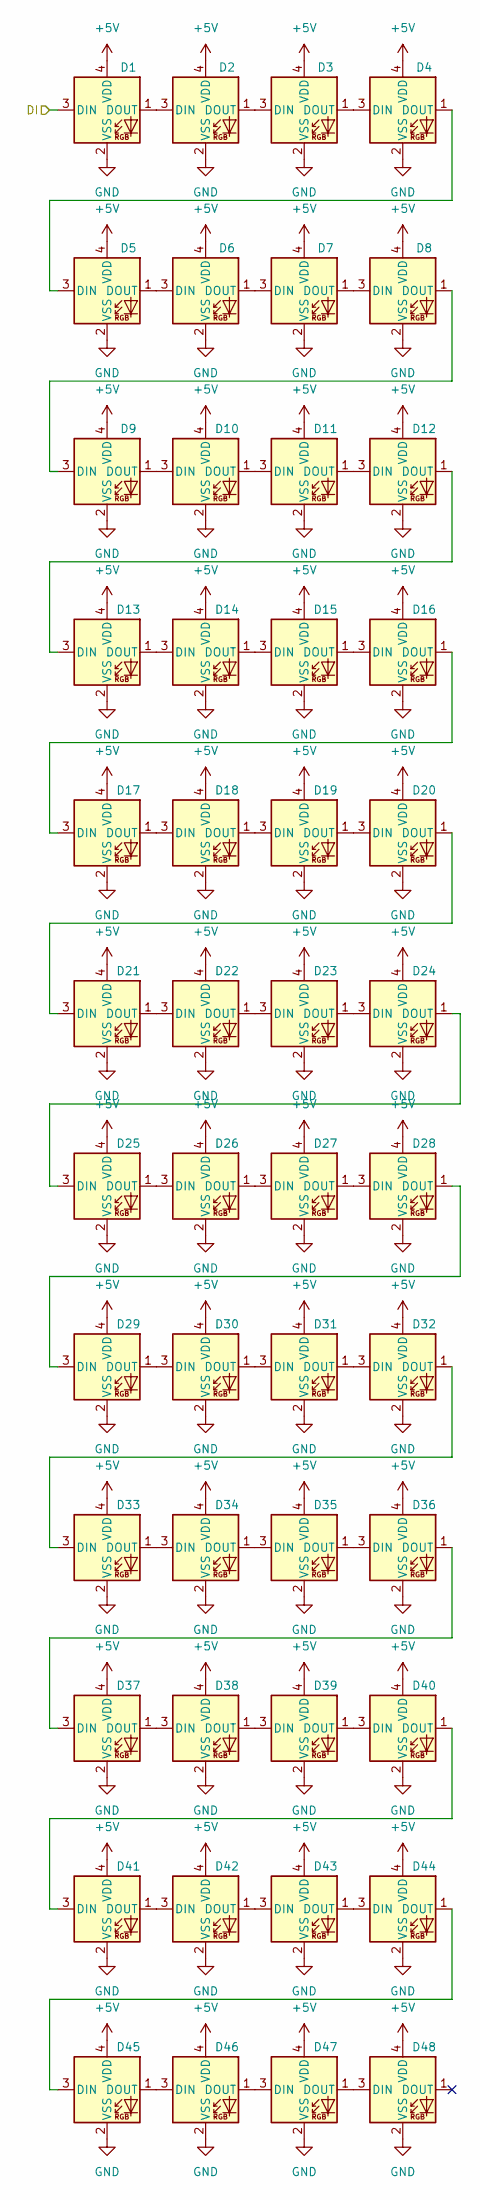
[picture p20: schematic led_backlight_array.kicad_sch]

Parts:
D1, D2, D3, D4, D5, D6, D7, D8, D9, D10, D11, D12, D13, D14, D15, D16, D17, D18, D19, D20, D21, D22, D23, D24, D25, D26, D27, D28, D29, D30, D31, D32, D33, D34, D35, D36, D37, D38, D39, D40, D41, D42, D43, D44, D45, D46, D47, D48: WS2812B-2020; LED_WS2812B-2020_PLCC4_2.0x2.0mm; LCSC PN C965555

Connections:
+5V: D1.4 (VDD), D2.4 (VDD), D3.4 (VDD), D4.4 (VDD), D5.4 (VDD), D6.4 (VDD), D7.4 (VDD), D8.4 (VDD), D9.4 (VDD), D10.4 (VDD), D11.4 (VDD), D12.4 (VDD), D13.4 (VDD), D14.4 (VDD), D15.4 (VDD), D16.4 (VDD), D17.4 (VDD), D18.4 (VDD), D19.4 (VDD), D20.4 (VDD), D21.4 (VDD), D22.4 (VDD), D23.4 (VDD), D24.4 (VDD), D25.4 (VDD), D26.4 (VDD), D27.4 (VDD), D28.4 (VDD), D29.4 (VDD), D30.4 (VDD), D31.4 (VDD), D32.4 (VDD), D33.4 (VDD), D34.4 (VDD), D35.4 (VDD), D36.4 (VDD), D37.4 (VDD), D38.4 (VDD), D39.4 (VDD), D40.4 (VDD), D41.4 (VDD), D42.4 (VDD), D43.4 (VDD), D44.4 (VDD), D45.4 (VDD), D46.4 (VDD), D47.4 (VDD), D48.4 (VDD); also elsewhere on the board
DI: D1.3 (DIN); also elsewhere on the board
GND: D1.2 (VSS), D2.2 (VSS), D3.2 (VSS), D4.2 (VSS), D5.2 (VSS), D6.2 (VSS), D7.2 (VSS), D8.2 (VSS), D9.2 (VSS), D10.2 (VSS), D11.2 (VSS), D12.2 (VSS), D13.2 (VSS), D14.2 (VSS), D15.2 (VSS), D16.2 (VSS), D17.2 (VSS), D18.2 (VSS), D19.2 (VSS), D20.2 (VSS), D21.2 (VSS), D22.2 (VSS), D23.2 (VSS), D24.2 (VSS), D25.2 (VSS), D26.2 (VSS), D27.2 (VSS), D28.2 (VSS), D29.2 (VSS), D30.2 (VSS), D31.2 (VSS), D32.2 (VSS), D33.2 (VSS), D34.2 (VSS), D35.2 (VSS), D36.2 (VSS), D37.2 (VSS), D38.2 (VSS), D39.2 (VSS), D40.2 (VSS), D41.2 (VSS), D42.2 (VSS), D43.2 (VSS), D44.2 (VSS), D45.2 (VSS), D46.2 (VSS), D47.2 (VSS), D48.2 (VSS); also elsewhere on the board
unnamed: D1.1 (DOUT), D2.3 (DIN)
unnamed: D2.1 (DOUT), D3.3 (DIN)
unnamed: D3.1 (DOUT), D4.3 (DIN)
unnamed: D4.1 (DOUT), D5.3 (DIN)
unnamed: D5.1 (DOUT), D6.3 (DIN)
unnamed: D6.1 (DOUT), D7.3 (DIN)
unnamed: D7.1 (DOUT), D8.3 (DIN)
unnamed: D8.1 (DOUT), D9.3 (DIN)
unnamed: D9.1 (DOUT), D10.3 (DIN)
unnamed: D10.1 (DOUT), D11.3 (DIN)
unnamed: D11.1 (DOUT), D12.3 (DIN)
unnamed: D12.1 (DOUT), D13.3 (DIN)
unnamed: D13.1 (DOUT), D14.3 (DIN)
unnamed: D14.1 (DOUT), D15.3 (DIN)
unnamed: D15.1 (DOUT), D16.3 (DIN)
unnamed: D16.1 (DOUT), D17.3 (DIN)
unnamed: D17.1 (DOUT), D18.3 (DIN)
unnamed: D18.1 (DOUT), D19.3 (DIN)
unnamed: D19.1 (DOUT), D20.3 (DIN)
unnamed: D20.1 (DOUT), D21.3 (DIN)
unnamed: D21.1 (DOUT), D22.3 (DIN)
unnamed: D22.1 (DOUT), D23.3 (DIN)
unnamed: D23.1 (DOUT), D24.3 (DIN)
unnamed: D24.1 (DOUT), D25.3 (DIN)
unnamed: D25.1 (DOUT), D26.3 (DIN)
unnamed: D26.1 (DOUT), D27.3 (DIN)
unnamed: D27.1 (DOUT), D28.3 (DIN)
unnamed: D28.1 (DOUT), D29.3 (DIN)
unnamed: D29.1 (DOUT), D30.3 (DIN)
unnamed: D30.1 (DOUT), D31.3 (DIN)
unnamed: D31.1 (DOUT), D32.3 (DIN)
unnamed: D32.1 (DOUT), D33.3 (DIN)
unnamed: D33.1 (DOUT), D34.3 (DIN)
unnamed: D34.1 (DOUT), D35.3 (DIN)
unnamed: D35.1 (DOUT), D36.3 (DIN)
unnamed: D36.1 (DOUT), D37.3 (DIN)
unnamed: D37.1 (DOUT), D38.3 (DIN)
unnamed: D38.1 (DOUT), D39.3 (DIN)
unnamed: D39.1 (DOUT), D40.3 (DIN)
unnamed: D40.1 (DOUT), D41.3 (DIN)
unnamed: D41.1 (DOUT), D42.3 (DIN)
unnamed: D42.1 (DOUT), D43.3 (DIN)
unnamed: D43.1 (DOUT), D44.3 (DIN)
unnamed: D44.1 (DOUT), D45.3 (DIN)
unnamed: D45.1 (DOUT), D46.3 (DIN)
unnamed: D46.1 (DOUT), D47.3 (DIN)
unnamed: D47.1 (DOUT), D48.3 (DIN)

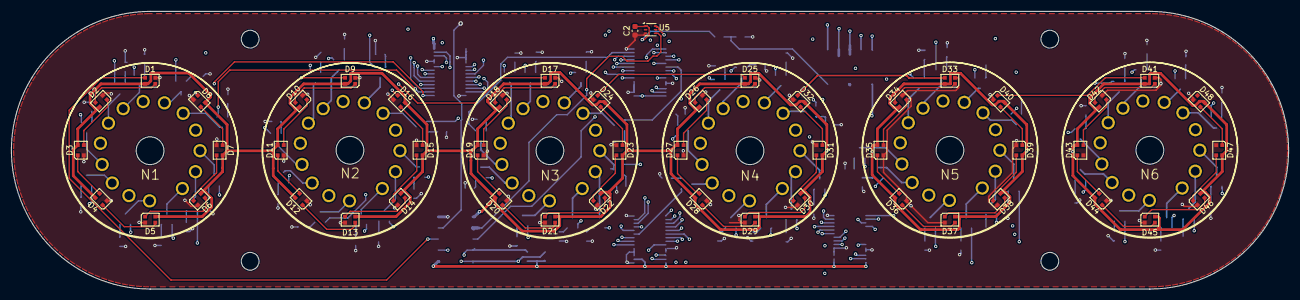
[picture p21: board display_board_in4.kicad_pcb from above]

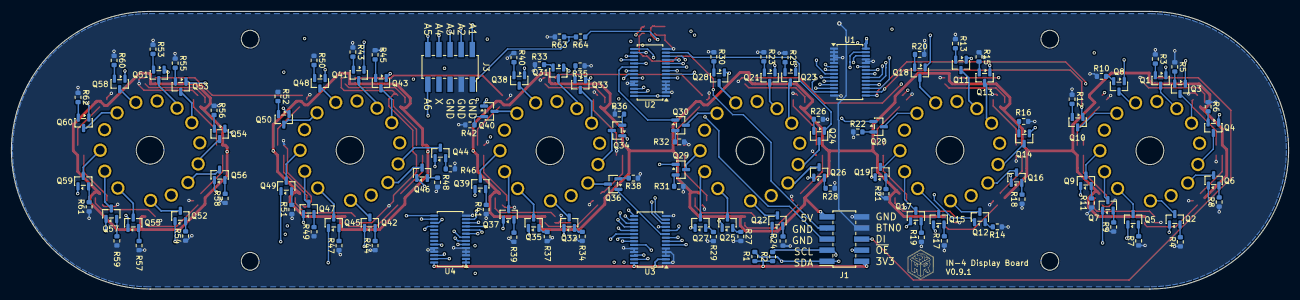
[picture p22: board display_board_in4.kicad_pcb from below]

Board: 4 copper layers, 230.0 x 50.0 mm, 190 parts (130 on the bottom side), 243 nets.

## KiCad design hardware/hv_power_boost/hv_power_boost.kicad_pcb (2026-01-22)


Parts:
C1, C2: 100u; C_1206_3216Metric; LCSC PN C15008
C3: 10u; C_0603_1608Metric; LCSC PN C109453
C4: 0.1u; C_0603_1608Metric; LCSC PN C36911391
C5: 180n; C_0603_1608Metric; LCSC PN C519442
C6: 18n; C_0603_1608Metric; LCSC PN C519551
C7: 33p; C_0603_1608Metric; LCSC PN C107047
C8: 1n; C_0603_1608Metric; LCSC PN C100040
C9: 1u; C_0603_1608Metric; LCSC PN C106248
C10: 0.1u/200V; C_1206_3216Metric; LCSC PN C113894
C11, C12: 0.47u/200V; C_1206_3216Metric; LCSC PN C725802
C13: NC; C_0603_1608Metric; not fitted
D1: ES5EB; D_SMB; LCSC PN C437860
J1: X6511WVS-02H-C60D48R1; PinHeader_1x02_P2.54mm_Vertical_SMD_Pin1Right; LCSC PN C2883799
J2: X6511WVS-03H-C60D48R1; PinHeader_1x03_P2.54mm_Vertical_SMD_Pin1Right; LCSC PN C780061
L1: PSPMAA0805-100M-ANP; PowerInductor_8mmx8.5mm; LCSC PN C2962885
Q1: FDS2734; SOIC-8_3.9x4.9mm_P1.27mm; LCSC PN C606022
R1, R10: 50k; R_0603_1608Metric; LCSC PN C304067
R2: 25k; R_0603_1608Metric; LCSC PN C2828637
R3: 220k; R_0603_1608Metric; LCSC PN C217882
R4: 10k; R_0603_1608Metric; LCSC PN C217687
R5: 30k; R_0603_1608Metric; LCSC PN C2828685
R6, R7, R8: 0; R_0603_1608Metric; LCSC PN C304185
R9: LMJ12MF1P0R047; R_1206_3216Metric; LCSC PN C5121701
R11: 300; R_0603_1608Metric; LCSC PN C217952
U1: LM5155; WSON-12-1EP_3x2mm_P0.5mm_EP1x2.65; LCSC PN C545416

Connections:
GND: C1.2, C2.2, C3.2, C4.2, C5.2, C6.2, C7.2, C8.2, C9.1, C10.2, C11.2, C12.2, C13.2, J1.2, J2.1, R2.2, R3.2, R9.2, R11.2, U1.4 (PGND), U1.7 (AGND), U1.13 (EP)
unnamed: C6.1, R5.2
unnamed: C8.1, R6.1, R8.2
unnamed: D1.2 (A), L1.2, Q1.5 (D), Q1.6 (D), Q1.7 (D), Q1.8 (D)
unnamed: C10.1, C11.1, C12.1, D1.1 (K), J2.2, R10.1
unnamed: C1.1, C2.1, C3.1, C4.1, J1.1, L1.1, R1.1, U1.1 (BIAS)
unnamed: Q1.4 (G), R7.2
unnamed: Q1.1 (S), Q1.2 (S), Q1.3 (S), R8.1, R9.1
unnamed: C7.1, R5.1, U1.6 (COMP)
unnamed: R6.2, U1.5 (CS)
unnamed: C13.1, R10.2, R11.1, U1.8 (FB)
unnamed: R7.1, U1.3 (GATE)
unnamed: R3.1, U1.10 (RT)
unnamed: C5.1, U1.9 (SS)
unnamed: R1.2, R2.1, U1.12 (UVLO/EN/SYNC)
PWR_HV_VCC: C9.2, R4.1, U1.2 (VCC)
PW_GOOD: J2.3, R4.2, U1.11 (PGOOD)

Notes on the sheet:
UVLO_ON=4.5V UVLO_OFF=4.1V


Board: 2 copper layers, 35.4 x 23.4 mm, 30 parts (0 on the bottom side), 17 nets.

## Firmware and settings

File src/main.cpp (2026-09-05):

#include "esp_log.h"
#include "freertos/FreeRTOS.h"
#include "freertos/task.h"
#include "driver/gpio.h"

#include "nixie_driver.h"
#include "led_driver.h"
#include "audio_driver.h"
#include "daemons/display_daemon.h"
#include "daemons/audio_daemon.h"
#include "gasgauge_service.h"
#include "charger_controller.h"
#include "bq27441/bq27441.h"
#include "power_switch/gpio_power_switch.h"
#include "bq25601/bq25601.h"
#include "power_controller.h"
#include "system_controller.h"
#include "system_state.h"
#include "daemons/cli_daemon.h"
#include "daemons/input_daemon.h"
#include "web_server.h"
#include "wifi_manager.h"
#include "ntp_scheduler.h"
#include "nvs_flash.h"
#include "i2c_debug_config.h"

static const char *kLogTag = "main";

extern "C" void app_main(void)
{
    esp_log_level_set("*", ESP_LOG_INFO);

    ESP_LOGI(kLogTag, "Starting Nixie Clock System...");

    esp_err_t nvs_err = nvs_flash_init();
    if (nvs_err == ESP_ERR_NVS_NO_FREE_PAGES || nvs_err == ESP_ERR_NVS_NEW_VERSION_FOUND) {
        ESP_ERROR_CHECK(nvs_flash_erase());
        ESP_ERROR_CHECK(nvs_flash_init());
    } else {
        ESP_ERROR_CHECK(nvs_err);
    }

    HardwareHandles hw_handles = SystemController::init_hardware();
    
    // Driver injection points
    static Bq27441 gasgauge_driver(hw_handles.i2c_port);
    static GasgaugeService gasgauge_service(gasgauge_driver);
    static SystemState system_state;

    static LedDriver led_driver(hw_handles.led_rmt_channel, hw_handles.led_rmt_encoder);
    static NixieDriver nixie_driver;

    static AudioDriver audio_driver(hw_handles.audio_uart_port);
    static GpioPowerSwitch power_switch_driver;
    static Bq25601 charger_driver(hw_handles.i2c_port);

    bool gasgauge_ready = false;
    if (!i2c_debug::kDisableGasgauge) {
        GasgaugeDeviceInfo info;
        if (gasgauge_service.probe_device_info(info) && gasgauge_service.is_ready()) {
            if (gasgauge_service.configure_capacity(GasgaugeService::kDefaultCapacityMah, false)) {
                gasgauge_ready = true;
                ESP_LOGI(kLogTag, "Gasgauge probed and capacity configured");
            } else {
                ESP_LOGW(kLogTag, "Gasgauge probe OK but capacity configure failed");
            }
        } else {
            ESP_LOGW(kLogTag, "Gasgauge probe failed at boot; SystemController will retry");
        }
    } else {
        ESP_LOGW(kLogTag, "Gasgauge disabled");
    }

    static DisplayDaemon display_daemon(nixie_driver, led_driver, system_state);
    static PowerController power_controller(power_switch_driver);

    system_state.load();
    ClockSettings boot_settings = SystemState::defaults();
    system_state.get_settings(&boot_settings);

    static AudioDaemon audio_daemon(audio_driver, power_controller, boot_settings.volume);
    static ChargerController charger_controller(charger_driver);
    static SystemController system_controller(display_daemon, audio_daemon, system_state,
                                              i2c_debug::kDisableGasgauge ? nullptr : &gasgauge_service,
                                              gasgauge_ready,
                                              &charger_controller);
    display_daemon.set_system_queue(system_controller.get_queue());
    static WifiManager wifi_manager;
    static InputDaemon input_daemon(system_controller, &wifi_manager);

    ClockSettings settings;
    system_state.get_settings(&settings);
    system_controller.apply_settings(settings, nullptr);

    static CliDaemon cli_daemon(system_controller, charger_controller, gasgauge_service,
                                power_controller, system_state, audio_daemon);
    static WebServer web_server(system_controller, system_state, audio_daemon, wifi_manager);
    static NtpScheduler ntp_scheduler(wifi_manager, system_state);

    ESP_LOGI(kLogTag, "Starting Daemons...");
    power_controller.init();
    power_controller.set_hv_enabled(true);
    power_controller.set_dfplayer_enabled(true);
    vTaskDelay(pdMS_TO_TICKS(50));

    if (!i2c_debug::kDisablePca9685I2c) {
        nixie_driver.nixie_scan_start(hw_handles.i2c_port);
    } else {
        ESP_LOGW(kLogTag, "PCA9685 I2C disabled (nixie scan not started)");
    }

    display_daemon.start();
    audio_daemon.start();
    system_controller.start();
    wifi_manager.set_config_callbacks(
        [&system_controller](uint16_t code) { system_controller.enter_wifi_config_ui(code); },
        [&system_controller]() { system_controller.on_wifi_config_client_connected(); },
        [&system_controller]() { system_controller.exit_wifi_config_ui(); });
    wifi_manager.set_ntp_apply_callback([&system_controller](time_t utc) {
        return system_controller.apply_ntp_utc(utc, nullptr);
    });
    wifi_manager.start();
    ntp_scheduler.start();
    input_daemon.start();
    vTaskDelay(pdMS_TO_TICKS(100));
    charger_controller.init();
    vTaskDelay(pdMS_TO_TICKS(100));
    cli_daemon.start();
    vTaskDelay(pdMS_TO_TICKS(100));
    web_server.start();
    vTaskDelay(pdMS_TO_TICKS(100));

    ESP_LOGI(kLogTag, "System Running.");

    vTaskDelete(nullptr);
}

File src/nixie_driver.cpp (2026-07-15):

#include "nixie_driver.h"
#include "display_board_config.h"
#include "pca9685/pca9685.h"
#include "freertos/FreeRTOS.h"
#include "freertos/task.h"
#include "driver/gpio.h"
#include "esp_log.h"
#include "esp_timer.h"
#include "soc/gpio_reg.h"
#include <vector>

namespace
{
constexpr gpio_num_t kPca9685OePin = GPIO_NUM_4;
constexpr gpio_num_t kAnodeA0 = GPIO_NUM_9;
constexpr gpio_num_t kAnodeA1 = GPIO_NUM_10;
constexpr gpio_num_t kAnodeA2 = GPIO_NUM_11;
constexpr uint8_t kAnodeBlankAddress = 7;

constexpr float kPwmFrequencyHz = 200.0f;
constexpr uint32_t kAnodeScanHz = 1000;
constexpr uint32_t kAnodeFrameUs = 1000000 / kAnodeScanHz;

constexpr uint32_t kPwmUpdateHz = 100;
constexpr uint32_t kPwmUpdatePeriodMs = 1000 / kPwmUpdateHz;

constexpr uint32_t kAnodePinMask =
    (1U << kAnodeA0) | (1U << kAnodeA1) | (1U << kAnodeA2);

struct AnodeScanCtx
{
    size_t tube_index = 0;
};

AnodeScanCtx g_anode_ctx;
esp_timer_handle_t g_anode_timer = nullptr;
portMUX_TYPE g_anode_mux = portMUX_INITIALIZER_UNLOCKED;
uint32_t g_anode_tube_count = 6;
uint32_t g_anode_slot_us = kAnodeFrameUs / 6;

void select_anode(uint8_t address);

struct ChannelRef
{
    uint8_t chip_index;
    uint8_t channel;
};

std::array<std::array<ChannelRef, 10>, kMaxDisplayTubes> kTubeMap = {};
uint8_t g_active_tube_count = 6;
uint8_t g_active_pca_chip_count = 4;
bool kMapInitialized = false;

void init_sequential_mapping(uint8_t tube_count, uint8_t pca_chip_count)
{
    for (uint8_t tube = 0; tube < tube_count; ++tube) {
        for (uint8_t digit = 0; digit < 10; ++digit) {
            const uint8_t global = static_cast<uint8_t>(tube * 10 + digit);
            kTubeMap[tube][digit] = {static_cast<uint8_t>(global / 16),
                                     static_cast<uint8_t>(global % 16)};
        }
    }

    for (uint8_t tube = tube_count; tube < kMaxDisplayTubes; ++tube) {
        for (uint8_t digit = 0; digit < 10; ++digit) {
            kTubeMap[tube][digit] = {static_cast<uint8_t>(pca_chip_count), 0};
        }
    }
}

void init_default_mapping()
{
    if (kMapInitialized) {
        return;
    }

    const DisplayBoardProfile &profile = get_display_board_profile();
    g_active_tube_count = profile.tube_count;
    g_active_pca_chip_count = profile.pca_chip_count;
    g_anode_tube_count = profile.tube_count;
    g_anode_slot_us = kAnodeFrameUs / g_anode_tube_count;

    switch (profile.type) {
    case DisplayBoardType::IN14_8:
        // 80 cathodes (8 tubes x 10 digits) across 5 PCA9685 chips.
        init_sequential_mapping(profile.tube_count, profile.pca_chip_count);
        break;
    case DisplayBoardType::IN14_6:
        // 60 cathodes (6 tubes x 10 digits) across 4 PCA9685 chips.
        init_sequential_mapping(profile.tube_count, profile.pca_chip_count);
        break;
    case DisplayBoardType::IN4_6:
    default:
        // 60 cathodes (6 tubes x 10 digits) across 4 PCA9685 chips.
        init_sequential_mapping(profile.tube_count, profile.pca_chip_count);
        break;
    }

    kMapInitialized = true;
}

void init_anode_mux()
{
    gpio_config_t cfg = {};
    cfg.intr_type = GPIO_INTR_DISABLE;
    cfg.mode = GPIO_MODE_OUTPUT;
    cfg.pin_bit_mask = (1ULL << kAnodeA0) | (1ULL << kAnodeA1) | (1ULL << kAnodeA2);
    cfg.pull_down_en = GPIO_PULLDOWN_DISABLE;
    cfg.pull_up_en = GPIO_PULLUP_DISABLE;
    gpio_config(&cfg);
    select_anode(kAnodeBlankAddress);
}

void select_anode(uint8_t address)
{
    const uint32_t levels = ((address & 1U) << kAnodeA0) | (((address >> 1) & 1U) << kAnodeA1) |
                            (((address >> 2) & 1U) << kAnodeA2);
    portENTER_CRITICAL(&g_anode_mux);
    const uint32_t out = REG_READ(GPIO_OUT_REG);
    REG_WRITE(GPIO_OUT_REG, (out & ~kAnodePinMask) | levels);
    portEXIT_CRITICAL(&g_anode_mux);
}

void anode_timer_callback(void *arg)
{
    auto *ctx = static_cast<AnodeScanCtx *>(arg);
    // gpio_set_level(kPca9685OePin, 1);
    select_anode(kAnodeBlankAddress);
    select_anode(static_cast<uint8_t>(ctx->tube_index));
    // gpio_set_level(kPca9685OePin, 0);
    ctx->tube_index = (ctx->tube_index + 1) % g_anode_tube_count;
}

} // namespace

static const char *kTag = "NixieDriver";

NixieDriver::NixieDriver()
    : brightness_(255)
{
    for (size_t i = 0; i < digit_cache_.size(); ++i) {
        digit_cache_[i] = 0;
        tube_brightness_[i] = 255;
    }
    for (auto &ref : active_cathode_) {
        ref = {255, 255};
    }
}

void NixieDriver::display_time(uint8_t h, uint8_t m, uint8_t s)
{
    portENTER_CRITICAL(&mux_);
    digit_cache_[0] = h / 10;
    digit_cache_[1] = h % 10;
    digit_cache_[2] = m / 10;
    digit_cache_[3] = m % 10;
    digit_cache_[4] = s / 10;
    digit_cache_[5] = s % 10;
    pwm_dirty_ = true;
    portEXIT_CRITICAL(&mux_);
}

void NixieDriver::display_date(uint8_t yy, uint8_t mm, uint8_t dd)
{
    portENTER_CRITICAL(&mux_);
    digit_cache_[0] = yy / 10;
    digit_cache_[1] = yy % 10;
    digit_cache_[2] = mm / 10;
    digit_cache_[3] = mm % 10;
    digit_cache_[4] = dd / 10;
    digit_cache_[5] = dd % 10;
    pwm_dirty_ = true;
    portEXIT_CRITICAL(&mux_);
}

void NixieDriver::display_number(uint32_t number)
{
    portENTER_CRITICAL(&mux_);
    for (int i = static_cast<int>(g_active_tube_count) - 1; i >= 0; --i) {
        digit_cache_[static_cast<size_t>(i)] = number % 10;
        number /= 10;
    }
    pwm_dirty_ = true;
    portEXIT_CRITICAL(&mux_);
}

void NixieDriver::set_brightness(uint8_t brightness)
{
    portENTER_CRITICAL(&mux_);
    brightness_ = brightness;
    pwm_dirty_ = true;
    portEXIT_CRITICAL(&mux_);
}

void NixieDriver::set_digits(const std::array<uint8_t, 6> &digits)
{
    portENTER_CRITICAL(&mux_);
    for (size_t i = 0; i < digits.size(); ++i) {
        digit_cache_[i] = digits[i];
    }
    pwm_dirty_ = true;
    portEXIT_CRITICAL(&mux_);
}

void NixieDriver::set_digit_at(size_t tube_index, uint8_t digit)
{
    if (tube_index >= digit_cache_.size()) {
        return;
    }

    portENTER_CRITICAL(&mux_);
    digit_cache_[tube_index] = digit % 10;
    pwm_dirty_ = true;
    portEXIT_CRITICAL(&mux_);
}

void NixieDriver::set_tube_brightness(size_t tube_index, uint8_t scale)
{
    if (tube_index >= tube_brightness_.size()) {
        return;
    }

    portENTER_CRITICAL(&mux_);
    tube_brightness_[tube_index] = scale;
    pwm_dirty_ = true;
    portEXIT_CRITICAL(&mux_);
}

void NixieDriver::nixie_scan_start(i2c_port_t i2c_port)
{
    if (scan_task_) {
        return;
    }
    i2c_port_ = i2c_port;
    init_default_mapping();
    ESP_LOGI(kTag, "Starting Nixie scan");
    xTaskCreate(scan_task_entry, "nixie_scan", 4096, this, 6, &scan_task_);
}

void NixieDriver::scan_task_entry(void *param)
{
    auto *driver = static_cast<NixieDriver *>(param);
    driver->scan_loop();
}
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

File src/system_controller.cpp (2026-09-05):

#include "system_controller.h"
#include "button_config.h"
#include "esp_log.h"
#include <cmath>
#include <ctime>
#include <cstdio>
#include <cstring>
#include <sys/time.h>
#include "system_state.h"
#include "gasgauge_service.h"
#include "charger_controller.h"
#include "i2c_debug_config.h"
#include "wifi_credentials.h"
#include "i2c_bus.h"
#include "driver/i2c.h"
#include "driver/uart.h"
#include "driver/gpio.h"
#include "display_board_config.h"
#include "esp_timer.h"

static const char *TAG = "SystemController";

namespace {

bool in_hibernate_period(uint16_t now_minutes, const HibernationSettings &hibernation)
{
    const uint16_t start =
        static_cast<uint16_t>(hibernation.start_hour) * 60U + hibernation.start_minute;
    const uint16_t end =
        static_cast<uint16_t>(hibernation.end_hour) * 60U + hibernation.end_minute;
    if (start == end) {
        return false;
    }
    if (start < end) {
        return now_minutes >= start && now_minutes < end;
    }
    return now_minutes >= start || now_minutes < end;
}

bool hibernate_is_active(const ClockSettings &settings, uint8_t hour, uint8_t minute)
{
    if (!settings.hibernation.enabled) {
        return false;
    }
    const uint16_t now_minutes = static_cast<uint16_t>(hour) * 60U + minute;
    return in_hibernate_period(now_minutes, settings.hibernation);
}

} // namespace

// Timekeeping policy: maintain ESP32 system time (UTC) and periodically
// resync from the DS3231 (the ±2ppm truth source) to correct drift.
static constexpr uint32_t kResyncIntervalMs = 3600000; // 1 hour
static constexpr uint8_t kMaxReadFailures = 5;

// Convert a broken-down UTC time to a Unix epoch without relying on timegm()
// (not exposed by the default ESP-IDF newlib config). Days-from-civil per
// Howard Hinnant's algorithm.
static time_t tm_to_utc_epoch(const struct tm *t)
{
    int year = t->tm_year + 1900;
    unsigned month = static_cast<unsigned>(t->tm_mon + 1);
    unsigned day = static_cast<unsigned>(t->tm_mday);

    year -= (month <= 2);
    int era = (year >= 0 ? year : year - 399) / 400;
    unsigned yoe = static_cast<unsigned>(year - era * 400);
    unsigned doy = (153 * (month + (month > 2 ? -3 : 9)) + 2) / 5 + day - 1;
    unsigned doe = yoe * 365 + yoe / 4 - yoe / 100 + doy;
    int64_t days = static_cast<int64_t>(era) * 146097 + static_cast<int64_t>(doe) - 719468;

    return static_cast<time_t>(days * 86400 + t->tm_hour * 3600 + t->tm_min * 60 + t->tm_sec);
}

// Parse the firmware build timestamp (__DATE__ "Jun 17 2026", __TIME__
// "19:10:00") into a broken-down time. Treated as UTC; this is only a
// placeholder used to clear the OSF when running without a VBAT battery.
static void build_time_to_tm(struct tm *out)
{
    static const char kMonths[] = "JanFebMarAprMayJunJulAugSepOctNovDec";
    char month_str[4] = {0};
    int day = 1, year = 2025, hour = 0, min = 0, sec = 0;
    sscanf(__DATE__, "%3s %d %d", month_str, &day, &year);
    sscanf(__TIME__, "%d:%d:%d", &hour, &min, &sec);

    int mon = 0;
    for (int i = 0; i < 12; ++i) {
        if (strncmp(month_str, kMonths + i * 3, 3) == 0) {
            mon = i;
            break;
        }
    }

    *out = {};
    out->tm_year = year - 1900;
    out->tm_mon = mon;
    out->tm_mday = day;
    out->tm_hour = hour;
    out->tm_min = min;
    out->tm_sec = sec;
    out->tm_isdst = 0;
}

// Hardware Configuration
constexpr i2c_port_t kI2cPort = I2C_NUM_0;
constexpr gpio_num_t kI2cSda = static_cast<gpio_num_t>(6);
constexpr gpio_num_t kI2cScl = static_cast<gpio_num_t>(5);
constexpr uint32_t kI2cClockHz = 400000;

constexpr uart_port_t kUartPort = UART_NUM_1;
constexpr gpio_num_t kUartTx = static_cast<gpio_num_t>(42);
constexpr gpio_num_t kUartRx = static_cast<gpio_num_t>(41);
constexpr int kUartBaudRate = 9600;

constexpr gpio_num_t kRtcIntPin = static_cast<gpio_num_t>(2);
constexpr gpio_num_t kPca9685OePin = static_cast<gpio_num_t>(4);
constexpr gpio_num_t kAnodeA0 = static_cast<gpio_num_t>(9);
constexpr gpio_num_t kAnodeA1 = static_cast<gpio_num_t>(10);
constexpr gpio_num_t kAnodeA2 = static_cast<gpio_num_t>(11);
constexpr gpio_num_t kLedDataInPin = static_cast<gpio_num_t>(7);
constexpr uint32_t kRmtResolutionHz = 40000000; // 25ns resolution

HardwareHandles SystemController::init_hardware()
{
    ESP_LOGI(TAG, "Initializing Hardware...");
    HardwareHandles handles = {};

    // 1. Initialize I2C
    i2c_config_t i2c_conf = {};
    i2c_conf.mode = I2C_MODE_MASTER;
    i2c_conf.sda_io_num = kI2cSda;
    i2c_conf.scl_io_num = kI2cScl;
    i2c_conf.sda_pullup_en = GPIO_PULLUP_ENABLE;
    i2c_conf.scl_pullup_en = GPIO_PULLUP_ENABLE;
    i2c_conf.master.clk_speed = kI2cClockHz;
    ESP_ERROR_CHECK(i2c_param_config(kI2cPort, &i2c_conf));
    ESP_ERROR_CHECK(i2c_driver_install(kI2cPort, i2c_conf.mode, 0, 0, 0));
    i2c_bus_init(kI2cPort);
    handles.i2c_port = kI2cPort;
    ESP_LOGI(TAG, "I2C Initialized");

    // 2. Initialize UART
    uart_config_t uart_config = {};
    uart_config.baud_rate = kUartBaudRate;
    uart_config.data_bits = UART_DATA_8_BITS;
    uart_config.parity = UART_PARITY_DISABLE;
    uart_config.stop_bits = UART_STOP_BITS_1;
    uart_config.flow_ctrl = UART_HW_FLOWCTRL_DISABLE;
    uart_config.source_clk = UART_SCLK_DEFAULT;
    ESP_ERROR_CHECK(uart_param_config(kUartPort, &uart_config));
    ESP_ERROR_CHECK(uart_set_pin(kUartPort, kUartTx, kUartRx, UART_PIN_NO_CHANGE, UART_PIN_NO_CHANGE));
    ESP_ERROR_CHECK(uart_driver_install(kUartPort, 256, 0, 0, nullptr, 0));
    handles.audio_uart_port = kUartPort;
    ESP_LOGI(TAG, "UART Initialized");

    // 3. Initialize RTC Interrupt Pin
    gpio_config_t io_conf = {};
    io_conf.intr_type = GPIO_INTR_NEGEDGE; // RTC INT is active low
    io_conf.pin_bit_mask = (1ULL << kRtcIntPin);
    io_conf.mode = GPIO_MODE_INPUT;
    io_conf.pull_up_en = GPIO_PULLUP_ENABLE;
    ESP_ERROR_CHECK(gpio_config(&io_conf));
    ESP_LOGI(TAG, "RTC Interrupt Pin Initialized");

    // 4. Read upper display board type (GPIO19 / DISPLAY_TYPE) before MUX / PCA9685 init.
    init_display_type_adc();
    handles.display_board_type = get_display_board_type();
    ESP_LOGI(TAG, "Display Board Type: %s", display_board_type_name(handles.display_board_type));

    // 5. Initialize PCA9685 OE Pin
    gpio_config_t oe_conf = {};
    oe_conf.intr_type = GPIO_INTR_DISABLE;
    oe_conf.mode = GPIO_MODE_OUTPUT;
    oe_conf.pin_bit_mask = (1ULL << kPca9685OePin);
    oe_conf.pull_down_en = GPIO_PULLDOWN_DISABLE;
    oe_conf.pull_up_en = GPIO_PULLUP_ENABLE; // Pull up to disable by default
    ESP_ERROR_CHECK(gpio_config(&oe_conf));
    ESP_ERROR_CHECK(gpio_set_level(kPca9685OePin, 1)); // Disable output (Active LOW)
    ESP_LOGI(TAG, "PCA9685 OE Pin Initialized (Disabled)");
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

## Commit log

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2026-01-21 feat(cli): add help and reboot command
    [cli_daemon.cpp]
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2026-01-22 feat(hardware): add kicad design file to repository
    [display_board_in18.kicad_pcb, display_board_in18.kicad_sch, display_board_in4.csv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]
2026-01-22 doc(satasheet): add datasheets for design reference
    [Inductor Selection.xlsx, LM5155_56_Quickstart_Calculator_for_Boost_Converter_Design_V1_1_1.xlsx, LM5155_56_Quickstart_Calculator_for_Boost_Converter_Design_V1_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]
2026-01-22 fix(hardware): correct comment on schematic, change DZ3231 default address to 0x68
    [main_board.kicad_sch]
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2026-01-26 hardware(schematic): update in4 display board current limit resistor to 68kOhm, update pin connector to 2X5 pin, no more GND1 needed, it's non-isloated
    [display_board_in4.kicad_sch]
2026-01-26 hardware(sch): update hv boost output capacitor, update connector pinout
    [hv_power.kicad_sch, main_board.kicad_sch]
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2026-01-28 WIP(hardware): in4 display board routing
    [led_backlight_array.kicad_sch]
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2026-01-29 WIP(hardware): update in-4 display board
    [display_board_in4.kicad_sch, hv_power.kicad_sch, main_board.kicad_pcb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]
2026-01-29 WIP(hardware): in4 display board layout
    [display_board_in4.kicad_pcb]
2026-01-29 WIP(haedware): add TPS62177 buck converter for 3v3 regulation
    [main_board.kicad_sch]
2026-01-30 WIP(hardware): update main board and mainboard layout
    [hv_power.kicad_sch, main_board.kicad_pcb, main_board.kicad_sch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]
2026-02-02 chore(hardware): complete mainboard layout
    [main_board.kicad_pcb, main_board.kicad_sch]
2026-02-03 chore(hardware): shrink main board size to lower the PCB price
    [main_board.kicad_pcb]
2026-02-03 chore(hardware): update bom and LCSC SN
    [hv_power.kicad_sch, main_board.kicad_pcb, main_board.kicad_sch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]
2026-04-07 hardware(schematic): Update IN-4 schematic and layout
    [display_board_in4.kicad_pcb, display_board_in4.kicad_sch]
2026-04-07 hardware(schematic): update main control board schematic and layout
    [battery_charger.kicad_sch, hv_power.kicad_sch, main_board.kicad_pcb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]
2026-04-07 hardware(schematic): update hv boost board compensation value, update design document
    [LM5155_56_Quickstart_Calculator_for_Boost_Converter_Design_V1_1_2.xlsx, hv_power_boost.kicad_sch]
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2026-04-07 fix(led): fix the number of led to 48
2026-06-03 chore(sch): adjust 3v3, 5v and power switch solutions.
    [gasgauge.kicad_sch, hv_power.kicad_sch, hv_power_flyback.kicad_sch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]
2026-06-09 hardware(sch): update component package to 0402 as most as possable, layout is still need to complete
    [gasgauge.kicad_sch, hv_power_flyback.kicad_sch, main_board.kicad_pcb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]
2026-06-10 hardware(sch): fix CP2102 VBUS connection. This pin should connect to 5V
    [main_board.kicad_sch]
2026-06-11 fix(nixie): Fix anode scan feature, now the anode will scan at 1kHz, but the cathode only update in 100Hz.
    [main.cpp, nixie_driver.cpp, system_controller.cpp]
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2026-06-14 fix(gasgauge): extrace gasgauge from display daemon for better isolation and reduce the usage of I2C bus. Add I2CLock in each I2C module to reduce the collision change. Add CLI support for gasgauge r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
    [cli_daemon.cpp, display_daemon.h]
2026-06-16 fix(daemon): remove ina3221 current measurement feature for cost. Rename power_daemon to power_controller, the function is no longer a daemon, it's only a utility to turn-on/off the switch. Remove so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
    [cli_daemon.cpp, main.cpp]
2026-06-16 Add pull-up resistor for DS3231 interrupt pin
    [main_board.kicad_sch]
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2026-06-17 fix(system): fix compile error
    [system_controller.h]
2026-06-17 fix(rtc): reset OSF for battery less debug usage
    [system_controller.cpp]
2026-06-17 fix(rtc): change rtc read period to one hour
    [system_controller.cpp]
2026-06-17 hardware(imu): remove imu for more cost effective
    [main_board.kicad_sch]
2026-06-18 hardware(als): Add ALS sensor LTR-303ALS to detect light, add push button as input.
    [main_board.kicad_pcb, main_board.kicad_sch]
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2026-06-18 fix(led): fix the brightness is not apply for breath effect issue
    [display_daemon.h]
2026-06-18 fix(webUI): Use local time instead UTC time for setting
    [system_controller.cpp, system_controller.h]
2026-06-18 hardware(display): fix the rotation of IN-4 tube
    [display_board_in4.kicad_pcb]
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2026-06-20 fix(audio): fix the wrong pin assignment
    [system_controller.cpp]
2026-06-20 chore(audio): remove initialize check for DFPlayer, fix webUI sd track count command to flash file count, not sure why sd file count is not working. Also another thing is the query get more count the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
2026-06-22 hardware(display): add button and ALS sensor on display board, align the nixie tube
    [display_board_in4.kicad_pcb, display_board_in4.kicad_sch]
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2026-07-03 hardware(sch): add button and display board identification pin
    [display_board_in4.kicad_sch, main_board.kicad_pcb, main_board.kicad_sch]
2026-07-05 hardware(sch): update anode mux resistor to reach 2.4mA for each tube, update 10kOhm PN
    [hv_power_flyback.kicad_sch, nixie_anode_mux.kicad_sch]
2026-07-05 hardware(sch): update schamatic and layout for next update
    [display_board_in4.kicad_pcb, main_board.kicad_pcb, main_board.kicad_sch]
2026-07-06 chore(doc): add some comment and fix the RTC calibration period
    [main.cpp, system_controller.cpp]
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2026-07-06 chore(webui): add padding in left and right corner to avoid user mis-touch the setting
    [main.cpp, system_controller.cpp]
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2026-07-06 chore(dfplayer): fix dfplayer get sound track can not play even number issue, need to put file under mp3/ folder
    [cli_daemon.cpp]
2026-07-06 fix(webui): fix webui button issue and optimize nixie tube anode scanning into one line
    [nixie_driver.cpp]
2026-07-07 fix(nixie): fix time delay from mode changed, the time is not flush immediately so the user will feel some delay because original one need to wait another second to get updated result.
    [system_controller.cpp, system_controller.h]
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2026-07-07 WIP: update pcb and schematic
    [main_board.kicad_pcb, main_board.kicad_sch]
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2026-07-08 WIP: should be fix can not preview when setting issue, but seems like it is failed.
    [system_controller.cpp, system_controller.h]
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2026-07-10 fix(audio): Fix audio driver and track query can not show on WebUI issue
    [cli_daemon.cpp, main.cpp]
2026-07-12 WIP: schematic and layout
    [display_board_in4.kicad_pcb, display_board_in4.kicad_sch, main_board.kicad_pcb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]
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2026-07-14 chore(hw): update 5V boost circuit, always enable
    [main_board.kicad_pcb, main_board.kicad_sch]
2026-07-14 chore(hw): update HUSB238 current setting resistor from 10k to 10.5k
    [main_board.kicad_sch]
2026-07-15 fix(display): user feel lag when sliding the slider is because it originally use 'debounce' mechanism, now use 'throttle' mechanism to reduce the request but keep update the LED
    [system_controller.cpp, system_controller.h]
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2026-07-15 fix(hw): fix TPS63802 EN pin and MODE pin to always high (always enable and PWM mode), add titanium bulk capacitor for TPS61022 to prevent the input oscillation by datasheet noticed
    [main_board.kicad_sch]
2026-07-15 fix: fix compile issue
    [cli_daemon.cpp]
2026-07-15 fix(audio): the audio preview will write to NVS too frequenly, add a preview mechanism and upload to NVS untill user finger left the slidebar.
    [main_board.kicad_sch]
2026-07-15 chore(hw): update pcb layout
    [main_board.kicad_pcb]
2026-07-15 hardware(in4): update in4 display board layout, fix the in4 rotation angle
    [display_board_in4.kicad_pcb]
2026-07-15 Revert "fix(audio): the audio preview will write to NVS too frequenly, add a preview mechanism and upload to NVS untill user finger left the slidebar."
    This reverts commit b7e6f93589d40733cb0f5ded45be88eb26fd4a00.
    [main_board.kicad_sch]
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2026-07-15 fix(nixie): fix some time the tube will be all off by the PCA9685 OE pin is always high
    [nixie_driver.cpp, system_controller.cpp]
2026-07-15 WIP: HV boost circuit integrate into main board
    [hv_power.kicad_sch, main_board.kicad_pcb]
2026-07-16 fix(alarm): fix the alarm can not stop in hibernate mode bug
    [system_controller.cpp]
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2026-07-17 WIP: mainboard pcb layout
    [main_board.kicad_pcb, main_board.kicad_sch]
2026-07-20 WIP: update mainboard componemt LCSC PN
    [hv_power.kicad_sch, main_board.kicad_pcb, main_board.kicad_sch]
2026-07-20 WIP: update component LCSCPN
    [hv_power.kicad_sch, main_board.kicad_sch]
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2026-07-22 hw(main_board): update LCSC PN
    [hv_power.kicad_sch, main_board.kicad_pcb, main_board.kicad_sch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]
2026-07-22 hw(display-in4): update LCSC PN and component status
    [display_board_in4.kicad_pcb, display_board_in4.kicad_sch]
2026-07-24 fix(webui): remove volume adjustment slidebar, change into '+/-' button to adjust the volume
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2026-08-04 chore(hw): add resistor LCSC PN
    [display_board_in4.kicad_sch]
2026-08-05 fix(hw): update display board layout
    [display_board_in4.kicad_pcb]
2026-08-06 remove unused file, add case 3d model
    [OUTBOXX_B.STL, OUTBOXX_F.STL, display_board_in4.csv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]
2026-08-10 hw(sch): add input detect signal from TPS2121 to let ESP32 know which input is selected for HV power
    [main_board.kicad_pcb, main_board.kicad_sch]
2026-08-13 hardware(display): lockdown in4 display board version for manufacturing
    [display_board_in4.kicad_pcb]
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
